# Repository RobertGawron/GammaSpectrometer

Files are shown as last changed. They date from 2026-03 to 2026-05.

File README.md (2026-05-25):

# Silicon Photomultiplier Gamma Spectrometer

  

## Principle of operation

Gamma Spectrometer allows for the quantitative measurement of the amount of different isotopes in an analyzed sample.

It consists of a scintillator (a material that converts gamma particles into photons) and a photomultiplier that multiplies those photons and converts them into electric current pulses. By measuring the amplitude of these pulses, it is possible to calculate the original energy of the gamma ray that produced the pulse.

Sampling data over time and plotting its histogram reveals which radioactive isotopes are present in the measured sample and their respective ratios.

[More info.](./02_SystemArchitecture/SystemTheory/README.md)

## System Architecture and Technical Decisions

### Silicon photomultiplier vs traditional PMT

Conventional gamma spectrometers commonly use vacuum photomultiplier tubes (PMTs). These require high-voltage supplies in the kilovolt range, are mechanically fragile, and are sensitive to magnetic fields.

In this project, a Silicon Photomultiplier (SiPM) is used instead. The SiPM operates at significantly lower bias voltage (tens of volts rather than kilovolts), is mechanically robust, compact, and insensitive to magnetic fields. These characteristics simplify the power supply design and mechanical integration.

### Digital vs analog processing

Traditional spectrometers implement CR-RC shaping networks and peak detection entirely in analog hardware. This approach is cost-effective but offers limited flexibility, as parameter changes require hardware modification.

In this system, pulse shaping and peak detection are performed digitally after high-speed sampling. This increases flexibility and allows signal processing parameters to be modified in firmware without hardware changes. The trade-off is higher performance requirements for the ADC and the need for an FPGA rather than a microcontroller, which increases overall system cost.

## Hardware design verification

Hardware design analysis is performed using LTspice for circuit simulation and a Jupyter-based framework for numerical post-processing. These tools are used to validate the interaction between the SiPM, the analog front-end, and the system timing behavior before to PCB design. The goal is to verify theoretical models, evaluate noise and bandwidth limitations, and confirm that design requirements are satisfied.

[More info.](./05_Verification/ElectronicHardware/Simulation/README.md)

## Hardware

Architecture Overview

Tools: KiCad.

[More info.](./03_SubsystemDesign/ElectronicHardware/README.md)

## Software

Target FPGA: iCE40.

The project is developed using a **completely open-source** FPGA toolchain containerized in Docker.

* RTL Language: VHDL-2008
* Synthesis: [Yosys](https://github.com/YosysHQ/yosys), [GHDL](https://github.com/ghdl/ghdl)
* Place & Route: [nextpnr](https://github.com/YosysHQ/nextpnr)
* Formal Verification: [SymbiYosys](https://github.com/YosysHQ/sby), PSL assertions
* Unit Testing Framework: [VUnit](https://vunit.github.io/)

[More info.](./03_SubsystemDesign/DigitalLogic/README.md)

## Mechanical

The analog frontend requires a metal chassis for protection from electromagnetic interference and external light sources.

The scintillator crystal is mounted inside using a 3D-printed stand.

The crystal and SiPM are optically coupled using optical gel to minimize light pulse reflections at the interface

Tools: OpenSCAD and FreeCAD.

Picture below shows a render of the holder for the scintillator crystal.

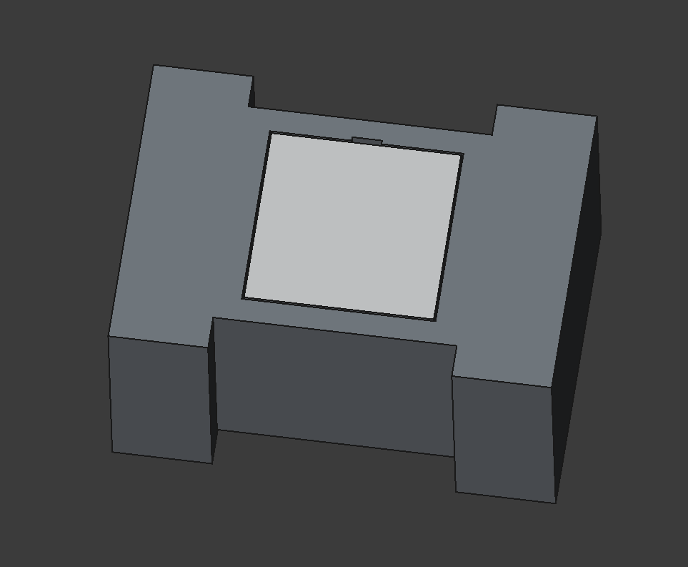
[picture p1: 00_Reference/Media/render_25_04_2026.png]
3d printed holder


[More info.](./03_SubsystemDesign/DetectorAssembly/README.md)

## DevOps

The development environment is containerized using Docker to avoid polluting the host machine with all the necessary software. The only two software tools that are not containerized are LTspice and KiCad.

[More info.](./07_DevOps/README.md)

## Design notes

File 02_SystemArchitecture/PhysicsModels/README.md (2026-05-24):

# Detector Architecture Studies

## Purpouse

The objective is to establish detector physics limits and evaluate
whether electronic performance exceeds fundamental scintillation limits.

$$
\sigma_{electronics} \ll \sigma_{scintillation}
$$

The detector physics sets the floor, electronics should not dominate it.
Anything significantly exceeding this margin is cost overhead, not performance gain.

---

## Study Index

| Study | File | Description |
|---|---|---|
| resolution_geometry_study | Analysis.ipynb | Resolution vs crystal/SiPM geometry |
| sipm_array_spectrum | Analysis.ipynb | Spectrum vs SiPM array size |
| dark_count | Analysis.ipynb | Temperature-dependent dark noise impact |

---

## Study 1 -- Resolution Geometry Study

### Question

How does crystal diameter and SiPM size affect statistical energy resolution?

### Parameters Swept

    Crystal diameters : [25.4, 38.0, 50.0] mm
    SiPM sizes        : [6.0, 10.0, 25.4] mm
    Scintillators     : NaI(Tl), LaBr3(Ce)

### Fixed Parameters

    Reference energy    : 0.662 MeV
    PDE                 : 0.35
    Optical efficiency  : 0.70

### Output

resolution_geometry_study

### Key Findings

* Larger SiPM relative to crystal -> better coverage -> lower FWHM
* LaBr3(Ce) consistently outperforms NaI(Tl) due to higher light yield
* At small crystal diameter (25.4 mm), even 6x6 mm SiPM gives meaningful coverage
* At large crystal diameter (50.0 mm), coverage drops significantly unless SiPM size is matched

---

## Study 2 -- SiPM Array Spectrum Study

### Scientific Question

How does increasing the number of SiPMs affect observable spectral peak separation and resolution?

### Resolution Scaling Model

Adding N identical SiPMs in parallel scales resolution as:

    FWHM(N) = FWHM_single / sqrt(N_sipm)

### SiPM Configurations Compared

    1 x 6x6 mm  ->  n_sipm = 1
    4 x 6x6 mm  ->  n_sipm = 4
    6 x 6x6 mm  ->  n_sipm = 6

### Output

sipm_array_spectrum
   
### Key Findings

    * Array scaling gives diminishing returns beyond ~4 SiPMs
    * Peak separation becomes clearly visible at n_sipm = 4
    * Background rate has visible impact at low-energy lines

---

## Study 3 -- Dark Count Noise Study

### Question

At what temperature does dark count noise begin to degrade
low-energy gamma detection?

### SiPM Device

    ON Semiconductor MICROFC-60035-SMT
    Active area  : 6 x 6 mm
    Microcell    : 35 um pitch
    Array config : 4 x SiPM

### Temperature Points

    [3, 21, 35] degC

### Low-Energy Isotopes Simulated

    Fe-55   :  5.9 keV
    Am-241  : 13.5 keV
    Cd-109  : 22.0 keV
    Ba-133  : 30.0 keV
    Am-241  : 59.5 keV

### Output

spectrum_dark_count_MICROFC60035

### Key Findings

    - Dark count rate increases significantly with temperature
    - At 35degC the noise floor begins to obscure sub-10 keV lines
    - Cooling to 3degC substantially suppresses the noise continuum

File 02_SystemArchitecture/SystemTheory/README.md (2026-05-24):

# Theoretical background

## Purpose
This folder contains the theoretical foundation for the SiPM-based gamma spectrometer.

It defines the mathematical models, signal relationships, and performance limits governing the detector, analog front-end (AFE), clocking, and ADC stages.

---

## Document Structure

* [SiPM and Charge Amplifier Readout](./SiPMAndCSA.md) - defines the detector and analog front-end signal model.
  * SiPM gain and charge generation: $$Q_{total} = N \cdot G \cdot q_e$$
  * Equivalent SiPM capacitance ($C_{SiPM}$)
  * Microcell recharge time constant ($\tau_{cell}$)
  * Charge-to-voltage conversion: $$V_{out} = \frac{Q_{in}}{C_f}$$
  * Feedback component relationships ($R_f, C_f$)

* [Analog Noise Analysis and Energy Resolution](./AnalogNoiseAnalysis.md) - defines the system noise budgeting methodology.
  * RMS noise definition and spectral density integration: $$V_{rms} = \sqrt{\int S_v^2(f) \, df}$$
  * Differential noise treatment
  * Input-referred noise (CSA and TIA)
  * Equivalent Noise Charge (ENC)
  * Root-sum-square (RSS) noise combination
  * ENOB conversion from SNR: $$ENOB = \frac{SNR - 1.76}{6.02}$$
  * Impact of electronic noise on energy resolution

* [Signal Processing and Sampling Theory](./SignalProcessingAndSampling.md)
  - Bandwidth vs rise time relationship:
    $$t_r \approx \frac{0.35}{f_{3dB}}$$
  - Sampling constraints and discrete-time representation
  - Rule of Three for amplitude reconstruction
  - Samples per pulse:
    $$N_{pulse} = \frac{5\tau}{T_s}$$
  - Digital integration SNR improvement:
    $$SNR \propto \sqrt{N}$$
  - Oversampling ratio:
    $$OSR = \frac{f_s}{2 \cdot BW}$$

* [Clock Jitter and SNR Limitation](./ClockJitterAnalysis.md) - defines timing-related performance limitations.
  * RMS jitter definition ($\sigma_t$)
  * Jitter-induced amplitude error derivation
  * Jitter-limited SNR equation: $$SNR_{jitter} = -20 \log_{10}(2\pi f_{in} \sigma_t)$$
  * ENOB relationship
  * Combination of multiple jitter sources (RSS combination)

* [ENOB and ADC Performance Limitations](./ENOBAndADCPerformance.md) - defines ADC-driven system constraints.
  * Ideal quantization SNR: $$6.02N + 1.76$$
  * Practical ENOB limits based on datasheet SNR
  * Margin definition ($\Delta$) for system design
  * Derivation of allowable noise from ENOB target: $$V_{noise,max} = \frac{V_{signal,rms}}{10^{SNR/20}}$$

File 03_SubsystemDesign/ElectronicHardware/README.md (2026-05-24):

# Purpose

The hardware consists of four main parts:

***Analog Processing***

Handles low-level currents produced by the sensor (typically 1uA - 1mA pulses, 10mV - 1V after amplification):

* **[LYSO Scintillator Crystal](https://www.ebay.fr/itm/251986066149)** - Converts gamma rays into visible light pulses through scintillation. The project uses eight crystals, each 22mm x 4mm x 4mm, stacked together into a single crystal assembly with a size of 22mm x 8mm x 16mm.
* **Silicon Photomultiplier: [MICROFC-60035-SMT-TR1 SiPM](https://www.onsemi.com/pdf/datasheet/microc-series-d.pdf)** - Converts light pulses from the scintillator crystal into electrical current pulses. The project uses four SiPMs in two channels; each channel contains two SiPMs in parallel.
* **Amplifier: [LTC6268-10](https://www.analog.com/media/en/technical-documentation/data-sheets/626810f.pdf)** -  can be configured either as a charge amplifier or as a transimpedance amplifier (TIA), depending on the selected feedback network. In the current design, the amplifier is configured as a charge amplifier.
  * **Charge Amplifier Configuration.** In this mode, the amplifier integrates the input current pulse generated by the SiPM and converts the total collected charge into a proportional output voltage.
    The output voltage is defined by the feedback capacitor:

    $$V_{out} = \frac{Q}{C_f}$$

    This can also be expressed as:

    $$V_{out} = \frac{1}{C_f} \int I(t) \, dt$$

    Where:
    
    **$Q_{in}$**: The total charge generated by the Silicon Photomultiplier (SiPM).

    **$C_f$**: The feedback capacitance of the integrator or transimpedance stage.

    **$I(t)$**: The time-dependent input current pulse from the detector.

  * **Transimpedance Amplifier (TIA) Configuration.** In this configuration, the output voltage is proportional to instantaneous input current:

    $$V_{out} = -I_{in} \cdot R_f$$

    Where:

    **$R_f$**: The feedback resistor that determines the gain of the transimpedance stage.

    **$I_{in}$**: The instantaneous input current flowing from the sensor into the amplifier.

* **Differential ADC Driver: [AD8139](https://www.analog.com/media/en/technical-documentation/data-sheets/AD8139.pdf)** - Converts the single-ended amplifier output into a differential signal suitable for the ADC input. It also sets the required common-mode voltage (1.5 V) needed by ADC.
* **Bias Supply** - Provides a stable and filtered 29 V bias voltage for the SiPM. The bias voltage is adjustable to compensate for temperature-dependent gain variation of the SiPM.
   * [MCP3221](https://ww1.microchip.com/downloads/en/devicedoc/20001732e.pdf) 12-bit I2C ADC measures the SiPM temperature via a thermistor. Since the SiPM gain varies with temperature, this measurement is used by FPGA to adjust the bias voltage
   * [MCP4725xxx-xCH](https://ww1.microchip.com/downloads/en/devicedoc/22039d.pdf) 12-bit I2C DAC generates a control voltage used to adjust the SiPM bias supply. This allows the FPGA to compensate temperature-induced gain variations of SiPM.
   * [LT8330IS6](https://www.analog.com/media/en/technical-documentation/data-sheets/lt8330.pdf) - dc/dc converter generates the raw high-voltage supply for the SiPM bias circuit.
   * [TPS7A49](https://www.ti.com/lit/ds/symlink/tps7a49.pdf?ts=1776866743000) - filters and regulates the output of the DC/DC converter, providing a low-noise and stable bias voltage for the SiPM. The output voltage is adjustable via the compensation DAC.
   * **Overcurrent Protection (TBD)** - Cuts bias voltage if SiPM is exposed to external light source, preventing sensor damage from excessive photocurrent

> **Note:** Analog pulse shaping and peak detection are not used - raw signal is digitized directly and processed in FPGA.

***Digital processing***

Performs high-speed sampling and real-time pulse analysis:

* **ADC: [AD9238](https://www.analog.com/media/en/technical-documentation/data-sheets/ad9238.pdf)** - 2-channel, 12-bit, 40 MSPS sampling rate. ch channel produces 480 Mbps (60 MB/s), resulting in 960 Mbps (120 MB/s) total sample data rate.
* **FPGA: [iCE40HX4K](https://www.latticesemi.com/en/Products/FPGAandCPLD/iCE40#_21E33C7EC0BD48AA80FE384ED73CC895)** - Real-time digital pulse processing (trapezoidal filtering, peak detection, histogram generation)
* **SPI Flash: [MX25L1606EM1I-12G](https://www.tme.eu/Document/90cf95a7114025302d33a68125e207ab/MX25L1606E.pdf)** - Stores FPGA configuration bitstream
* **SPI Port** - External header for FPGA programming
* **UART to USB Converter: [CH340X](https://cdn.sparkfun.com/assets/5/0/a/8/5/CH340DS1.PDF)** - Communication interface to PC.

**Clock Subsystem**

* [511JCA40M0000BAG](https://eu.mouser.com/datasheet/3/564/1/si510_11.pdf) 40MHz, 0.8ps Nom / 1ps Max jitter LVDS clock
* [SI53340-B-GM](https://eu.mouser.com/datasheet/3/564/1/Si5334x_datasheet.pdf)
* [PI6C49CB01Q2WEX](https://4donline.ihs.com/images/VipMasterIC/IC/DIOD/DIOD-S-A0009189280/DIOD-S-A0009189280-1.pdf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)

**Power Distribution**
* to be refined

# Circuit

Circuit

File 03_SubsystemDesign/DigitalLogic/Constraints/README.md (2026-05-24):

# Constraints

Constraint files for FPGA implementation, including:
* pin assignments
* timing constraints
* clock constraints
* location constraints
* I/O standards
* tool-specific constraints

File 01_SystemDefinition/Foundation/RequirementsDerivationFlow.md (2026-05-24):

## Purpose

This document is [the foundation for requirement IDs](../Requirements/)

---

## Derivation Flow

| Step | Detail / Value |
| :--- | :--- |
| **Measurement Intent** | First HW version, capability to be determined experimentally. |
| **Scintillator Selection** | NaI(Tl) 25.4 mm diameter, light yield 38,000 ph/MeV, cost-effective, good timing (230 ns decay) |
| **SiPM Selection** | 4 x MICROFC-60035-SMT (6x6 mm each), PDE 35%, cost-effective, effective coverage 28.4% |
| **Detector Physics Analysis** ($\sigma_{scintillation}$ calculated) | N_detected = 1755 PE @ 662 keV, $\sigma_{scintillation} = 2.39\%$, FWHM_statistical = 5.6% |
| **Electronics Noise Budget** ($\sigma_{electronics} \leq 0.18 \times \sigma_{scintillation}$) | Derived: $\sigma_{electronics} \leq 0.43\%$ RMS; Total degradation < 1.5% acceptable |
| **Bandwidth Derived** (from pulse shape) | SiPM t_cell = 95 ns -> f_-3dB ~= 3.5 MHz; ADC sampling at 40 MSPS adequate for pulse reconstruction |
| *ADC* | 12-bit, 40 MSPS |

**Detector Physics Analysis and Requirements Derivation**
(See: [Detector Physics Analysis and Requirements Derivation](./DetectorPhysicsAnalysis.md))

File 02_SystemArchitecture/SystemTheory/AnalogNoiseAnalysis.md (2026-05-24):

# Analog Noise Analysis and Energy Resolution

## 1. Purpose

Basis for analyzing analog front-end (AFE) noise.

---

## 2. Definitions

### 2.1 Noise Spectral Density and RMS Integration
Voltage noise spectral density $S_v(f)$ is expressed in units of:

$$\text{V} / \sqrt{\text{Hz}}$$

The RMS noise over a defined bandwidth from $f_{low}$ to $f_{high}$ is:

$$V_{rms} = \sqrt{\int_{f_{low}}^{f_{high}} S_v^2(f) \, df}$$

**Principles:**
* Spectral density must be squared before integration (working in the power domain).
* Integration must be performed in the linear domain.
* RMS noise is strictly bandwidth dependent.
* Integration limits must always be explicitly stated.

---

### 2.2 Bandwidth Definition
The integration bandwidth shall match the effective system bandwidth. For an ADC sampling at $f_s$:

$$f_{Nyquist} = \frac{f_s}{2}$$

Noise shall be integrated from DC to Nyquist unless limited by an analog anti-alias filter. If an anti-alias filter is present, the shaped spectral density is used:

$$S_{v,shaped}(f) = |H(f)| \cdot S_v(f)$$

The resulting $S_{v,shaped}^2(f)$ shall be used in the integration defined in Section 2.1.

---

### 2.3 Differential Noise
For differential ADC inputs:

$$V_{diff}(t) = V_P(t) - V_N(t)$$

All RMS noise calculations relevant to ADC performance shall be performed on the differential signal. The integration method defined in Section 2.1 applies to the differential spectral density.

---

### 2.4 Input-Referred Noise
The total integrated RMS noise may be referred to the detector domain.

**Transimpedance Amplifier (TIA):**

$$I_{noise,rms} = \frac{V_{noise,rms}}{R_f}$$

**Charge-Sensitive Amplifier (CSA):**

$$Q_{noise,rms} = V_{noise,rms} \cdot C_f$$

**Convert charge noise to electrons ($N_e$):**

$$N_e = \frac{Q_{noise,rms}}{e}$$

Where $e = 1.602 \times 10^{-19} \text{ C}$. This quantity represents the complete integrated analog front-end noise referred to the detector input.

---

### 2.5 Total RMS Noise (RSS Combination)
Independent noise sources shall be combined in variance form:

$$V_{total,rms} = \sqrt{V_1^2 + V_2^2 + V_3^2 + \dots}$$

**Assumptions:**
* Statistical independence.
* Gaussian distribution.
* No deterministic correlation.
* **Note:** Noise powers add, not amplitudes.

---

### 2.6 Integrated Noise vs Frequency (Cumulative Form)
To evaluate noise contribution as a function of bandwidth:

$$V_{rms}(f) = \sqrt{\int_{f_{low}}^{f} S_v^2(f') \, df'}$$

This representation allows for the identification of dominant frequency regions and verification of anti-alias filter effectiveness.

---

### 2.7 Conversion to SNR and ENOB
**Signal-to-Noise Ratio (SNR):**

$$SNR = 20 \log_{10} \left( \frac{V_{signal,rms}}{V_{noise,rms}} \right)$$

**Effective Number of Bits (ENOB):**

$$ENOB = \frac{SNR - 1.76}{6.02}$$

---

### 2.8 Equivalent Noise Charge (ENC)
For charge-based systems:

$$Q_{noise} = I_{noise,rms} \cdot \tau$$

$$N_e = \frac{Q_{noise}}{e}$$

**Where:**
* $\tau$: Shaping time constant.
* $e$: Elementary charge.

ENC provides a direct linkage between electronic noise and spectroscopy energy resolution.

---

### 2.9 Scintillation Statistical Limit

From Poisson statistics, the relative energy resolution is limited by the number of scintillation photons:

$$\frac{\sigma_E}{E} \propto \frac{1}{\sqrt{N_{ph}}}$$

This represents the **fundamental detector limit**.

Even with perfect electronics, the resolution cannot exceed this bound.

---

### 2.10 Electronics Contribution

Electronic noise introduces additional variance:

$$\sigma_{electronics}$$

Total variance combines in quadrature:

$$\sigma_{total}^2 = \sigma_{scintillation}^2 + \sigma_{electronics}^2$$

---

### 2.11 Physics-Limited Regime

If:

$$\sigma_{electronics} \ll \sigma_{scintillation}$$

Then:

$$\sigma_{total} \approx \sigma_{scintillation}$$

In this regime, system performance is limited by scintillator physics rather than electronics.

The design goal of the analog front-end is therefore to ensure:

$$ENC_{electronics} \ll ENC_{detector}$$
ENC provides a direct linkage between electronic noise and system energy resolution.

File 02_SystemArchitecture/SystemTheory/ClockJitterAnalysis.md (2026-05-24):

# Clock Jitter and SNR Limitation

## 1. Purpose

Theoretical basis for clock jitter analysis.

---

## 2. Definitions

### 2.1 Signal-to-Noise Ratio (SNR)

In power terms:

$$
\mathrm{SNR} = \frac{P_{\mathrm{signal}}}{P_{\mathrm{noise}}}
$$

In decibel form:

$$
\mathrm{SNR}_{dB} = 10 \log_{10}\left(\frac{P_{\mathrm{signal}}}{P_{\mathrm{noise}}}\right)
$$

For voltage quantities (equal impedance):

$$
\mathrm{SNR}_{dB} = 20 \log_{10}\left(\frac{V_{\mathrm{signal,rms}}}{V_{\mathrm{noise,rms}}}\right)
$$

---

### 2.2 RMS Clock Jitter

RMS jitter represents the statistical standard deviation of sampling time uncertainty.

If an ideal sampling instant occurs at time $t_0$, the actual sampling time is:

$$
t = t_0 + \Delta t
$$

where $\Delta t$ is a random timing deviation.

The RMS jitter is defined as:

$$
\sigma_t = \sqrt{E[(\Delta t)^2]}
$$

where $E[\cdot]$ denotes the expectation operator.

---

## 2.3 Derivation of Jitter-Limited SNR

Consider a sinusoidal input signal:

$$
x(t) = A \sin(2\pi f_{in} t)
$$

If sampling occurs with time error $\Delta t$, the amplitude error is:

$$
\Delta x = \frac{dx}{dt} \cdot \Delta t
$$

The derivative of the signal is:

$$
\frac{dx}{dt} = A \cdot 2\pi f_{in} \cos(2\pi f_{in} t)
$$

Thus:

$$
\Delta x = A \cdot 2\pi f_{in} \cos(2\pi f_{in} t) \cdot \Delta t
$$

The RMS value of $\cos(\cdot)$ is $1/\sqrt{2}$.

Therefore, jitter-induced RMS noise is:

$$
V_{\mathrm{jitter,rms}} = \frac{A}{\sqrt{2}} \cdot 2\pi f_{in} \sigma_t
$$

Signal RMS:

$$
V_{\mathrm{signal,rms}} = \frac{A}{\sqrt{2}}
$$

Thus:

$$
\mathrm{SNR} = \frac{V_{\mathrm{signal,rms}}}{V_{\mathrm{jitter,rms}}}
= \frac{1}{2\pi f_{in} \sigma_t}
$$

In decibel form:

$$
\mathrm{SNR}_{dB} = -20 \log_{10}(2\pi f_{in} \sigma_t)
$$

This shows jitter-induced SNR degradation increases linearly with input frequency.

---

## 2.4 Derivation of ENOB Formula

For an ideal N-bit ADC with full-scale peak-to-peak range $V_{FS,pp}$:

$$
\mathrm{LSB} = \frac{V_{FS,pp}}{2^N}
$$

Quantization noise RMS (uniform distribution):

$$
V_{q,rms} = \frac{\mathrm{LSB}}{\sqrt{12}}
$$

For a full-scale sine wave:

$$
V_{\mathrm{signal,rms}} = \frac{V_{FS,pp}}{2\sqrt{2}}
$$

Thus:

```math
\mathrm{SNR} =
\frac{V_{\mathrm{signal,rms}}}{V_{q,rms}}
=
\frac{\frac{V_{FS,pp}}{2\sqrt{2}}}
{\frac{V_{FS,pp}}{\sqrt{12} \cdot 2^N}}
=
\sqrt{\frac{3}{2}} \cdot 2^N
```

In decibel form, the ideal SNR for an $N$-bit converter is:

$$SNR_{dB} = 6.02N + 1.76$$

Rearranging to solve for the **Effective Number of Bits (ENOB)** based on measured SNR:

$$ENOB = \frac{SNR_{dB} - 1.76}{6.02}$$

## 2.5 Total SNR Combination
When multiple independent noise sources exist (e.g., ADC intrinsic noise and jitter noise), noise powers add in the linear domain.

If:

$$SNR_{ADC}$$
$$SNR_{jitter}$$

Then:

$$\frac{1}{SNR_{total,linear}} = \frac{1}{SNR_{ADC,linear}} + \frac{1}{SNR_{jitter,linear}}$$

Where:
$$SNR_{linear} = 10^{SNR_{dB}/10}$$

Convert back:

$$SNR_{total,dB} = 10 \log_{10}(SNR_{total,linear})$$

Noise powers must always be summed in linear scale.

---

## 2.6 RSS Jitter Combination
If multiple independent RMS jitter sources exist:

$$\sigma_{total} = \sqrt{\sigma_1^2 + \sigma_2^2 + \sigma_3^2 + \dots}$$

This follows from variance addition:

$$\sigma_{total}^2 = \sigma_1^2 + \sigma_2^2 + \sigma_3^2 + \dots$$

Valid only for uncorrelated jitter sources.

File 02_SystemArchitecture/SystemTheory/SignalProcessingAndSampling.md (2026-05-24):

# Signal Processing and Sampling Theory

## 1. Purpose

Defines the relationship between analog bandwidth, pulse dynamics, sampling rate, digital reconstruction, and processing gain.

This document covers the time-domain and discrete-time constraints of the spectroscopy system.

---

## 2. Bandwidth and Rise Time Relationship

For a first-order system:

$$t_r \approx \frac{0.35}{f_{3dB}}$$

Where:
* $t_r$: 10%-90% rise time.
* $f_{3dB}$: -3 dB bandwidth.

The constant arises from:

$$t_r = \frac{\ln(9)}{\omega_{3dB}} = \frac{2.2}{2\pi f_{3dB}}$$

Engineering Interpretation:
* Higher bandwidth -> faster rise time.
* Excess bandwidth increases integrated noise.

Bandwidth must preserve signal dynamics without unnecessarily increasing noise.

---

## 3. Sampling Theory

ADC sampling frequency:

$$f_s$$

Sampling period:

$$T_s = \frac{1}{f_s}$$

Samples across rising edge:

$$N_{rise} = \frac{t_r}{T_s}$$

---

## 4. The Rule of Three

For reliable amplitude estimation:

$$N_{rise} \ge 3$$

Reason:
* 1 sample -> no slope information.
* 2 samples -> unstable interpolation.
* 3+ samples -> reliable curve fitting and peak detection.

This requirement arises from discrete-time approximation limits.

---

## 5. Total Samples per Pulse

Pulse duration approximately:

$$T_{pulse} \approx 5\tau$$

Total samples per pulse:

$$N_{pulse} = \frac{5\tau}{T_s}$$

Determines:
* Digital integration capability
* Energy estimation stability
* Pile-up discrimination

---

## 6. Digital Integration and SNR Improvement

When integrating $N$ independent samples:

$$SNR \propto \sqrt{N}$$

Because:

$$\sigma_{avg} = \frac{\sigma}{\sqrt{N}}$$

Oversampling improves effective resolution through processing gain.

---

## 7. ADC Resolution vs Sampling Rate

Two orthogonal improvement mechanisms:

Increasing ADC bits:
* Reduces quantization noise
* Improves SNR by ~6 dB per bit

Increasing sampling rate:
* Increases $N$
* Improves SNR by $\sqrt{N}$ after integration

Total system variance:

$$\sigma_{total}^2 = \sigma_{detector}^2 + \sigma_{AFE}^2 + \sigma_{ADC}^2 + \sigma_{quantization}^2$$

Dominant variance determines performance limit.

---

## 8. Oversampling Ratio (OSR)

$$OSR = \frac{f_s}{2 \cdot BW}$$

Higher OSR:
* Improves digital filtering flexibility
* Reduces in-band noise after decimation
* Improves amplitude estimation stability

ADC speed enables digital processing gain even if analog bandwidth is lower.

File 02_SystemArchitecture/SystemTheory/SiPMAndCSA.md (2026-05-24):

# SiPM and Charge Amplifier Readout

## 1. Purpose
Theoretical background of the Silicon Photomultiplier (SiPM) and its readout using a charge-sensitive amplifier.

---
## 2. Definitions

### 2.1 Silicon Photomultiplier (SiPM) Operation

When a photon is absorbed in a microcell, it may trigger an avalanche process, producing a fixed amount of charge. The charge generated by a single avalanche event is given by:

$$Q_{1ph} = G \cdot q_e$$

**Where:**
* $G$: SiPM gain (number of charge carriers generated during one avalanche event).
* $q_e$: Elementary charge ($1.602 \times 10^{-19}$ C).

> **Note:** The gain $G$ is typically provided in the device datasheet and depends on the applied overvoltage.

For multiple detected photons:

$$Q_{total} = N \cdot G \cdot q_e$$

**Where:**
* $N$: Number of triggered microcells (approximately equal to detected photons under low light conditions).

Thus, the SiPM behaves as a quantized charge generator.

---

### 2.2 SiPM Capacitance
Since all microcells are connected in parallel, the SiPM exhibits a total equivalent capacitance ($C_{SiPM}$). This capacitance arises from the junction capacitance of each microcell and the parallel combination of all cells.

$C_{SiPM}$ influences:
* Bandwidth
* Noise
* Stability of the front-end amplifier

In a charge amplifier configuration, however, the gain does not depend directly on $C_{SiPM}$.

---

### 2.3 Microcell Recharge Time Constant
After an avalanche event, each microcell must recharge through its internal quench resistor. This follows exponential recovery behavior characterized by the microcell time constant:

$$\tau_{cell} = R_q \cdot C_{cell}$$

**Where:**
* $R_q$: Internal quench resistor.
* $C_{cell}$: Microcell capacitance.

> **Note:** The gain $\tau_{cell}$ is typically provided in the device datasheet.

The value of $\tau_{cell}$ affects the maximum count rate, pulse shape, and dynamic response.

---

### 2.4 Charge Amplifier Principle
To convert the SiPM charge pulse into a measurable voltage, a charge-sensitive amplifier (CSA) is used. In an ideal charge amplifier:

$$V_{out} = \frac{Q_{in}}{C_f}$$

Substituting the SiPM charge expression:

$$V_{out} = \frac{N \cdot G \cdot q_e}{C_f}$$

**This shows that:**
1. The output voltage is proportional to the number of detected photons.
2. The gain is determined only by the feedback capacitor $C_f$.
3. The detector capacitance $C_{SiPM}$ does not set the signal amplitude.

---

### 2.5 Feedback Capacitor ($C_f$)
In a charge-sensitive amplifier (CSA), the output voltage is determined by the input charge and the feedback capacitance:

$$V_{out} = \frac{Q_{in}}{C_f}$$

For an SiPM, the input charge generated by $N$ detected photons is:

$$Q_{in} = N \cdot G \cdot q_e$$

Combining both equations:

$$V_{out} = \frac{N \cdot G \cdot q_e}{C_f}$$

Rearranging to determine the required feedback capacitance for a specific target voltage:

$$C_f = \frac{N \cdot G \cdot q_e}{V_{out}}$$

**Thus, the feedback capacitor is selected based on:**
* Expected maximum number of detected photons ($N$).
* SiPM gain ($G$) from the datasheet.
* Desired output voltage amplitude ($V_{out}$).

The value of $C_f$ directly sets the charge-to-voltage conversion gain of the system.

---

### 2.6 Feedback Resistor ($R_f$)
The feedback resistor determines the discharge rate of the feedback capacitor and therefore the pulse decay time. The decay time constant of the charge amplifier is:

$$\tau = R_f \cdot C_f$$

To ensure accurate charge integration, the amplifier time constant is chosen relative to the SiPM microcell recharge time constant ($\tau_{cell}$):

$$\tau \ge k \cdot \tau_{cell}$$

**Where:**
* $\tau_{cell}$ is provided in the datasheet.
* $k$ is typically selected between 3 and 5.

Solving for the feedback resistor:

$$R_f = \frac{\tau}{C_f}$$

Once $C_f$ is determined and the desired shaping time $\tau$ is selected, the required feedback resistor can be calculated.

Design Considerations
* **$C_f$**: Defines signal amplitude and dynamic range. Larger capacitance prevents saturation but lowers sensitivity.
* **$R_f$**: Defines pulse width and maximum count rate capability. Lower resistance allows for faster counting but may increase electronic noise.
* Both parameters must be selected considering noise, bandwidth, and stability constraints of the operational amplifier.

---

### 2.8 Detector Shot Noise (SiPM)
The dominant intrinsic noise mechanism of a SiPM is shot noise associated with dark current. The RMS shot noise current is given by:

$$i_{shot,rms} = \sqrt{2q I_{dark} \Delta f}$$

**Where:**
* $q$: Elementary charge ($1.602 \times 10^{-19} \text{ C}$).
* $I_{dark}$: Detector dark current.
* $\Delta f$: Effective noise bandwidth.

Shot noise arises from the discrete nature of charge carriers and follows Poisson statistics.

**Key Properties:**
* Shot noise is proportional to the square root of dark current.
* Shot noise increases with bandwidth.
* Shot noise is statistically independent from electronic amplifier noise.

This contribution must be included in the total noise RSS calculation when modeling full system performance.

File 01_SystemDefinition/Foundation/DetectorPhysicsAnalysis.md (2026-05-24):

# Detector Physics Analysis and Requirements Derivation

## Purpose

The objective is to establish detector physics limits and evaluate
whether electronic performance exceeds fundamental scintillation limits.

The fundamental design principle is:

$$
\sigma_{electronics} \ll \sigma_{scintillation}
$$

The detector physics sets the performance floor. Electronics should not
dominate it. Anything significantly exceeding this margin is cost overhead,
not performance gain.

---

## Design Flow Overview

The correct systems engineering flow for gamma spectrometer design:

1. Measurement Intent
2. Isotope Identification Requirements
3. Energy Resolution Requirements
4. Scintillator Selection (based on resolution, density, cost, ruggedness)
5. Crystal Geometry Selection (volume vs weight tradeoff)
6. SiPM Selection (PDE, dark count, size, radiation hardness)
7. Detector Physics Analysis (calculate sigma_scintillation)
8. Electronics Noise Budget Derivation (sigma_electronics <= 0.3 x sigma_scintillation)
9. Bandwidth Derivation (from SiPM pulse shape)
10. ADC Requirements Derivation (ENOB, sampling rate)
11. Component Selection (meets derived requirements)

---

## Section 1 - Scintillator Selection

### Selection Criteria

Scintillator selection is driven by multiple competing requirements:

| Property | Impact | Tradeoff |
|---|---|---|
| Light yield (photons/MeV) | Higher -> better resolution | Usually inversely related to density |
| Density (g/cm^3) | Higher -> better detection efficiency | Heavier, may reduce light yield |
| Decay time (ns) | Shorter -> higher count rate capability | May have lower light yield |
| Emission wavelength (nm) | Must match SiPM PDE peak | Material constraint |
| Hygroscopicity | Non-hygroscopic -> easier handling | May limit material choices |

### Common Scintillator Properties

| Material | Light Yield (ph/MeV) | Density (g/cm^3) | Decay Time (ns) | Emission Peak (nm) | Hygroscopic |
|---|---|---|---|---|---|
| NaI(Tl) | 38,000 | 3.67 | 230 | 415 | Yes |
| LaBr3(Ce) | 63,000 | 5.08 | 16 | 380 | Yes |
| CsI(Tl) | 54,000 | 4.51 | 1000 | 550 | Slightly |
| LYSO | 32,000 | 7.10 | 40 | 420 | No |
| BGO | 8,500 | 7.13 | 300 | 480 | No |

Choice: [diameter 1 inch x 1 inch NaI(Tl) Scintillator, Energy Resolution: <=7.5%@662keV(Cs-137)](https://www.ost-photonics.com/product/diameter-1-inch-x-1-inch-naitl-scintillator/)
Reason: Cost/performance ratio. Price is a key factor because scintillator crystals are expensive ($95+ USD).

## Section 2 - SiPM Selection

### Selection Criteria

| Property | Impact | Target |
|---|---|---|
| Photon Detection Efficiency (PDE) | Higher -> more detected photons -> better resolution | Match to scintillator emission |
| Active area | Larger -> better coverage -> better resolution | Match to crystal geometry |
| Dark count rate (DCR) | Lower -> less noise at low energy | Temperature-dependent |
| Microcell size | Smaller -> lower crosstalk, higher DCR | Tradeoff: 15-50 um typical |
| Gain | Higher -> easier amplification | Must not saturate electronics |
| Timing resolution | Better -> improved coincidence performance | Not critical for spectroscopy |
| Radiation hardness | Critical for high-dose environments (not the case of this spectrometer) | Mission-dependent |
| Operating voltage | Lower -> simpler bias supply | 25-35 V typical for modern SiPMs |

Choice: [MICROFC-60035-SMT](https://www.onsemi.com/pdf/datasheet/microc-series-d.pdf)
Reason: Cost/performance ratio. SiPM are expensive ($12+ USD for 6x6mm variant).

## Section 3 - Detector Physics Calculation

### Statistical Energy Resolution Model

This subsections models the theoretical lower bound on energy resolution
assuming Poisson fluctuations in the number of detected photons dominate.

---

### Step 1 - Reference Gamma Energy

For system verification and calibration:

Cs-137 reference line:

$$
E_{\gamma} = 662 \text{ keV} = 0.662 \text{ MeV}
$$

---

### Step 2 - Scintillation Photon Production

Total photons produced by scintillation:

$$
N_{photons} = LY \times E_{\gamma}
$$

Where LY is the scintillator light yield.

For selected scintillators:

| Scintillator | Calculation | N_photons |
|---|---|---|
| NaI(Tl) | 38,000 x 0.662 | 25,156 |
| LaBr3(Ce) | 63,000 x 0.662 | 41,706 |

Note: the light output of the scintillator is a function of the deposited Gamma energy.

---

### Step 3 - Optical Collection Efficiency

Not all produced photons reach the SiPM face.

Optical efficiency factor (accounts for reflector losses, absorption):

$$
\eta_{optical} \approx 0.70
$$

Geometric coverage fraction:

$$
C_{geom} = \frac{A_{SiPM}}{A_{crystal}}
$$

Effective coverage including optical transport losses:

$$
C_{eff} = C_{geom} \times \eta_{optical}
$$

Collected photons reaching SiPM active area:

$$
N_{collected} = N_{photons} \times C_{eff}
$$

---

### Step 4 - SiPM Photon Detection

Photon Detection Efficiency (PDE) from MICROFC-60035-SMT datasheet:

$$
PDE \approx 0.35
$$

Number of detected photoelectrons:

$$
N_{detected} = N_{collected} \times PDE
$$

Full expression (combining all stages):

$$
N_{detected} = LY \times E_{\gamma} \times C_{geom} \times \eta_{optical} \times PDE
$$

---

### Step 5 - Statistical Fluctuation (Poisson Statistics)

Photoelectron generation follows Poisson statistics.

Standard deviation:

$$
\sigma_{N} = \sqrt{N_{detected}}
$$

Relative RMS fluctuation:

$$
\sigma_{rel} = \frac{\sigma_{N}}{N_{detected}} = \frac{1}{\sqrt{N_{detected}}}
$$

---

### Step 6 - Convert RMS to FWHM

### Derivation of FWHM Conversion Factor

The constant 2.355 comes from Gaussian distribution geometry:

For a Gaussian with standard deviation sigma, the FWHM is:

$$
FWHM = 2\sqrt{2\ln(2)} \times \sigma \approx 2.355 \times \sigma
$$

This assumes the energy distribution is Gaussian, which is valid when:
- N_detected >> 100 (Central Limit Theorem applies)
- Poisson distribution -> Gaussian for large N

For our configuration (N_detected = 1755), this assumption is valid.

Energy resolution is conventionally expressed as Full Width at Half Maximum (FWHM).

For a Gaussian distribution:

$$
FWHM = 2.355 \times \sigma
$$

Therefore:

$$
FWHM = 2.355 \times \sigma_{rel}
$$

Convert to percentage:

$$
FWHM = \frac{2.355}{\sqrt{N_{detected}}} \times 100
$$

---

### Step 7 - Final Statistical Resolution Formula

$$
\boxed{
FWHM = \frac{2.355}{\sqrt{N_{detected}}} \times 100
}
$$

Where:

$$
N_{detected} = LY \times E_{\gamma} \times C_{geom} \times \eta_{optical} \times PDE
$$

This is the **detector statistical limit** -- the physics floor
that cannot be improved by electronics.

---

### Step 8 - Worked Example (Selected Configuration)

Configuration:

| Parameter | Value |
|---|---|
| Scintillator | NaI(Tl) |
| Light yield | 38,000 photons/MeV |
| Crystal diameter | 25.4 mm |
| SiPM model | MICROFC-60035-SMT |
| SiPM size | 6.0 x 6.0 mm |
| PDE | 0.35 |
| Optical efficiency | 0.70 |
| Reference energy | 662 keV (0.662 MeV) |

**Calculation:**

Crystal face area:

$$
A_{crystal} = \pi \times \left(\frac{25.4}{2}\right)^2 = \pi \times 12.7^2 \approx 506.7 \text{ mm}^2
$$

SiPM configuration: 4 x (6x6 mm) array

Single SiPM active area:

$$
A_{SiPM,single} = 6.0^2 = 36.0 \text{ mm}^2
$$

Total SiPM array active area:

$$
A_{SiPM,total} = 4 \times 36.0 = 144.0 \text{ mm}^2
$$

Geometric coverage:

$$
C_{geom} = \frac{144.0}{506.7} \approx 0.284 \text{ (28.4\%)}
$$

Effective coverage:

$$
C_{eff} = 0.284 \times 0.70 \approx 0.199
$$

Photons produced:

$$
N_{photons} = 38000 \times 0.662 = 25156
$$

Detected photoelectrons:

$$
N_{detected} = 25156 \times 0.199 \times 0.35 \approx 1755
$$

Statistical RMS:

$$
\sigma_{rel} = \frac{1}{\sqrt{1755}} = \frac{1}{41.89} \approx 0.0239
$$

$$
\sigma_{scintillation} = 2.39\% \text{ RMS}
$$

Statistical FWHM:

$$
FWHM = \frac{2.355}{\sqrt{1755}} \times 100 \approx 5.6\%
$$

**Result:**

For NaI(Tl) 25.4 mm + 4 x MICROFC-60035-SMT (6x6 mm array):

$$
\boxed{
\sigma_{scintillation} = 2.39\% \text{ RMS at 662 keV}
}
$$

$$
\boxed{
FWHM_{statistical} = 5.6\%
}
$$

This is the detector physics floor.

### Step 9 - SiPM Configuration Comparison

| SiPM Size | Area (mm^2) | Effective Coverage (%) | $$\sigma$$ | FWHM  |
|---|---|---|---|---|
| 3x3 mm | 9 | 1.24% | 9.56% | 22.51% |
| 6x6 mm | 36 | 4.97% | 4.78% | 11.25% |
| array of 4 x (6x6 mm) | 144 | 19.89% | 2.39% | 5.63% |

Choice: array of 4 x (6x6 mm) [MICROFC-60035-SMT](https://www.onsemi.com/pdf/datasheet/microc-series-d.pdf)
Reason: Cost/performance ratio.

### Step 10 - Model Assumptions and Limitations

This model includes **statistical photon noise only**.

Effects **NOT** included:

| Effect | Impact on Resolution |
|---|---|
| Electronic noise | Adds in quadrature: $\sigma_{total}^2 = \sigma_{scint}^2 + \sigma_{elec}^2$ |
| Dark count rate (DCR) | Adds false counts, raises low-energy noise floor |
| Optical crosstalk | Inflates apparent N_detected, degrades resolution |
| After-pulsing | Distorts pulse shape, affects energy measurement |
| Crystal non-proportionality | Introduces energy-dependent bias |
| Optical non-uniformity | Position-dependent resolution variation |
| Temperature effects on PDE | Shifts gain and resolution |
| SiPM gain non-uniformity | Cell-to-cell variation |

Therefore:

$$
FWHM_{calculated} \leq FWHM_{measured}
$$

The calculated value is a **theoretical lower bound**.

Real measured resolution will always be larger due to additional noise sources.

---

## Section 4 - Electronics Requirements Derivation

### Noise Budget Allocation

From Section 3, we determined (for 4 x 6x6 mm SiPM array):

$$\sigma_{scintillation} = 2.39\% \text{ RMS}$$

### Design Rule

To meet minimal degradation:

$$\sigma_{electronics} \leq 0.18 \times \sigma_{scintillation}$$

This ensures total degradation is limited to 1.5%:

$$\sigma_{total} = \sqrt{\sigma_{scint}^2 + \sigma_{elec}^2}$$

### Calculate Electronics Budget

$$\sigma_{electronics} \leq 0.18 \times 2.39\% = 0.43\% \text{ RMS}$$

$$\sigma_{electronics} \leq 0.43\%$$

### Verify Degradation

If electronics contributes 0.43% RMS:

$$\sigma_{total} = \sqrt{2.39^2 + 0.43^2} = \sqrt{5.71 + 0.18} = \sqrt{5.89} \approx 2.427\%$$

Degradation:

$$\frac{2.427 - 2.39}{2.39} \times 100 \approx 1.5\%$$

This meets the requirement (≤ 1.5% degradation threshold).

### Derived Requirement

$$\boxed{\sigma_{electronics} \leq 0.43 \text{ percent RMS of full-scale energy}}$$

This is traceable to detector physics.

---

### Detector-Limited SNR

Convert detector resolution to SNR:

For FWHM ~= 5.6% (4 x 6x6 mm SiPM array):

$$\sigma = \frac{FWHM}{2.355} = \frac{5.6}{2.355} \approx 2.38\%$$

Equivalent SNR:

$$SNR = \frac{1}{\sigma} = \frac{1}{0.0238} \approx 42$$

In dB:

$$SNR_{dB} = 20 \log_{10}(42) \approx 32.5 \text{ dB}$$

**The detector physics limit is approximately 32.5 dB SNR at 662 keV.**

---

### ADC Specification Comparison

Typical ADC specifications:

- Ideal ADC SNR: 65-70 dB
- Detector-limited SNR: ~32.5 dB
- Margin: ~37 dB

**Conclusion:**

The ADC intrinsic noise floor is **not** the system bottleneck.
Detector photon statistics dominate system resolution.
Even with improved detector (4 SiPM array), ADC still has ~37 dB margin.

### Important Clarification on ENOB

ENOB (Effective Number of Bits) is a **sinusoidal continuous-wave metric**
based on SNR of a full-scale sine wave.

Gamma spectroscopy resolution is a **statistical pulse-area metric**
based on Poisson photon counting.

**These are not directly equivalent.**

Blindly applying ENOB-based ADC selection can lead to over-specification
of dynamic performance relative to detector physics.

---

## Section 5 -- Bandwidth Requirements Derivation

### SiPM Microcell Pulse Physics

After a photon triggers an avalanche in a SiPM microcell:

1. Microcell capacitance discharges rapidly (~1 ns)
2. Quench resistor stops the avalanche
3. Microcell recharges exponentially toward bias voltage

The recharge voltage follows:

$$
V(t) = V_{bias} \left(1 - e^{-t / \tau_{cell}}\right)
$$

Where the cell time constant is:

$$
\tau_{cell} = R_{quench} \times C_{cell}
$$

For MICROFC-60035-SMT (from datasheet):

| Parameter | Value |
|---|---|
| Microcell recharge time constant | tau_cell ~= 95 ns |
| Anode-cathode capacitance | C = 3400 pF |
| Dark count rate (21degC) | ~100 kHz/mm^2 |

**Important:**

tau_cell = 95 ns is the exponential recharge constant of each microcell.

It defines the **pulse tail time constant** at the anode.

It does NOT mean the pulse rise time is 95 ns (rise is faster).

The tail dominates the observable pulse envelope.

**Note:** When using 4 SiPMs in parallel, the individual microcell time constant
remains the same (95 ns). The combined pulse shape is the sum of 4 independent
SiPM pulses, but the characteristic time constant does not change.

---

### ADC Sampling Constraint

Selected ADC sampling rate: 40 MSPS

Sampling period:

$$
T_s = \frac{1}{40 \times 10^6} = 25 \text{ ns}
$$

To adequately reconstruct pulse shape:

**Required: 3 to 5 samples across rising edge**

Therefore required analog rise time:

$$
t_{rise,min} = 3 \times T_s = 75 \text{ ns}
$$

$$
t_{rise,pref} = 5 \times T_s = 125 \text{ ns}
$$

Target rise time range:

$$
t_{rise} \approx 75 \text{ to } 125 \text{ ns}
$$

This naturally aligns with tau_cell ~= 95 ns.

---

### Bandwidth Derivation

Using standard rise time to bandwidth conversion:

$$
f_{3dB} \approx \frac{0.35}{t_{rise}}
$$

For t_rise = 100 ns:

$$
f_{3dB} \approx \frac{0.35}{100 \times 10^{-9}} = 3.5 \text{ MHz}
$$

**Derived Bandwidth Requirement:**

$$
\boxed{
f_{3dB} = 3 \text{ to } 6 \text{ MHz}
}
$$

**Note:** Bandwidth requirement is independent of SiPM array size.
It is determined by pulse shape (tau_cell) and ADC sampling constraints,
not by detector resolution.

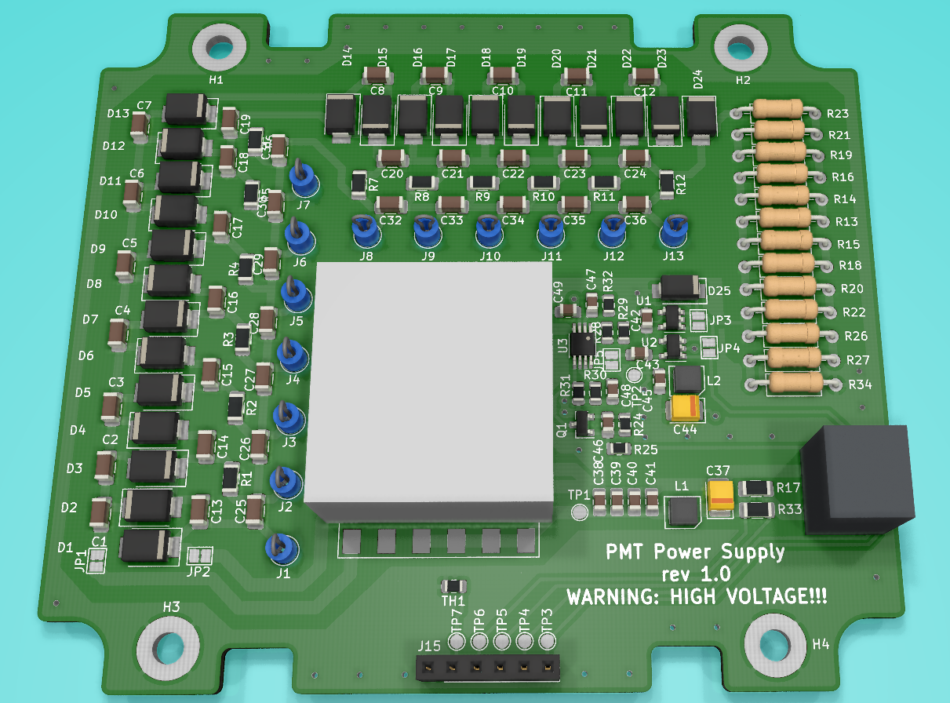
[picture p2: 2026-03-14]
00_Reference/Media/render_10_11_2020.png

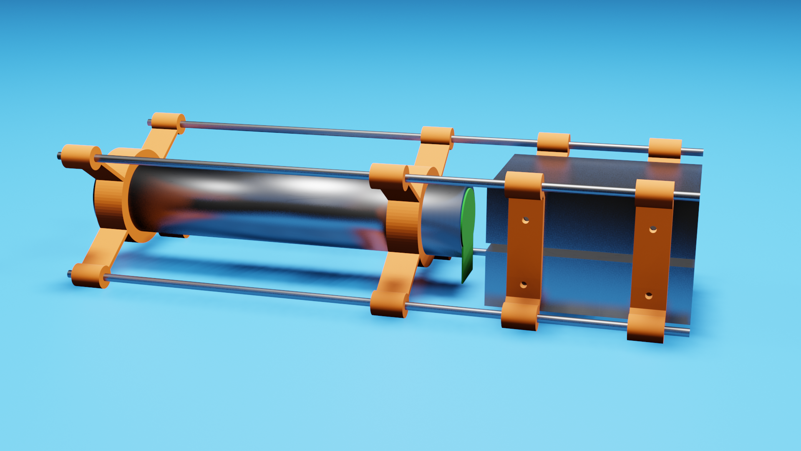
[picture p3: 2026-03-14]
00_Reference/Media/render_28_10_2020.png

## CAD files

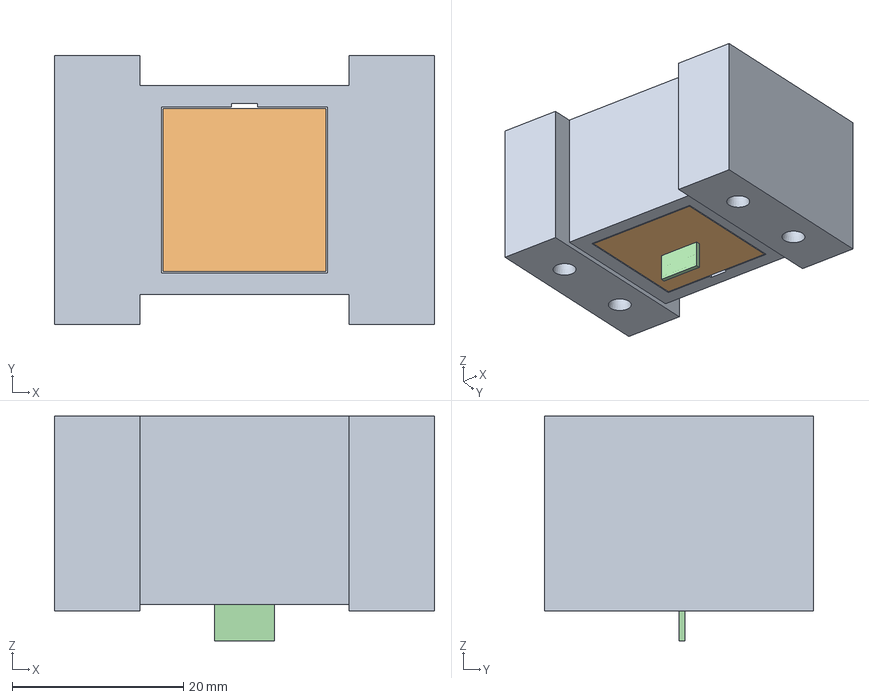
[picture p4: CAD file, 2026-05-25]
03_SubsystemDesign/DetectorAssembly/01_Models_Source/02_FreeCAD/01_ScintillationCrystalHolder/Main.FCStd
44.4 x 31.4 x 26.2 mm
MICROFC-60035-SMT-TR1
MICROFC-60035-SMT-TR002
MICROFC-60035-SMT-TR003
MICROFC-60035-SMT-TR004

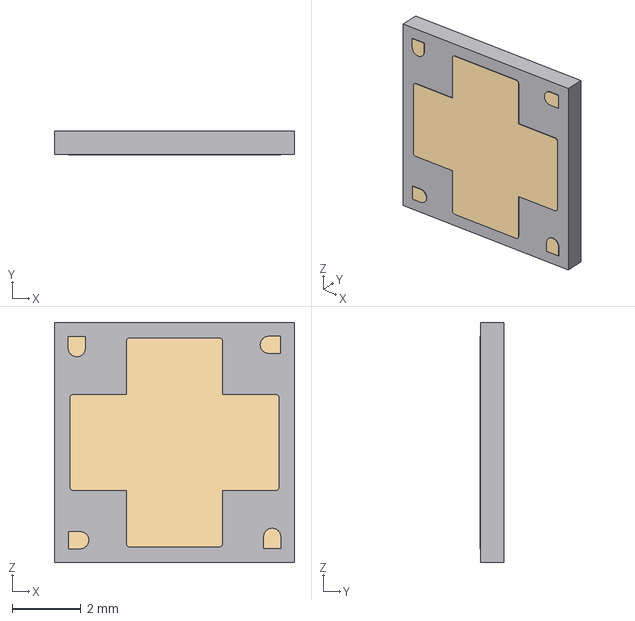
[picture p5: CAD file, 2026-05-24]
03_SubsystemDesign/DetectorAssembly/02_Models_COTS/MICROFC-60035-SMT-TR1.stp
7.00 x 0.7 x 7.00 mm

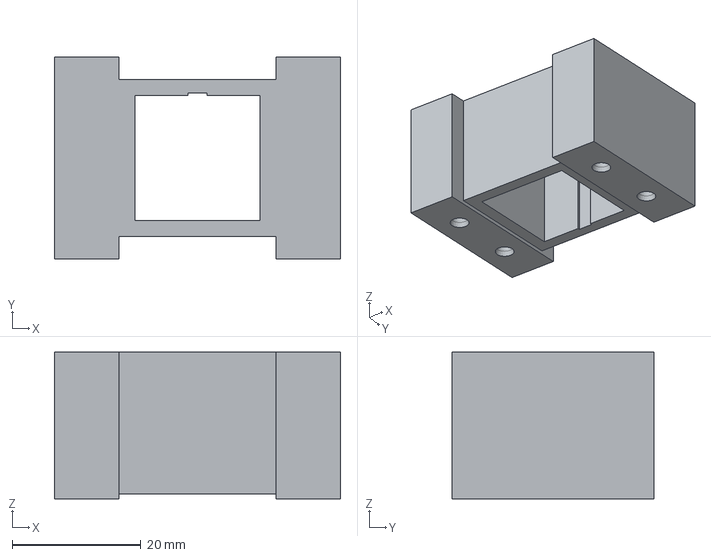
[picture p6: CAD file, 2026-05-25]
04_Implementation/DetectorAssembly/Manufacturing/STEP/01_ScintillationCrystalHolder/Holder.step
44.4 x 31.4 x 22.8 mm

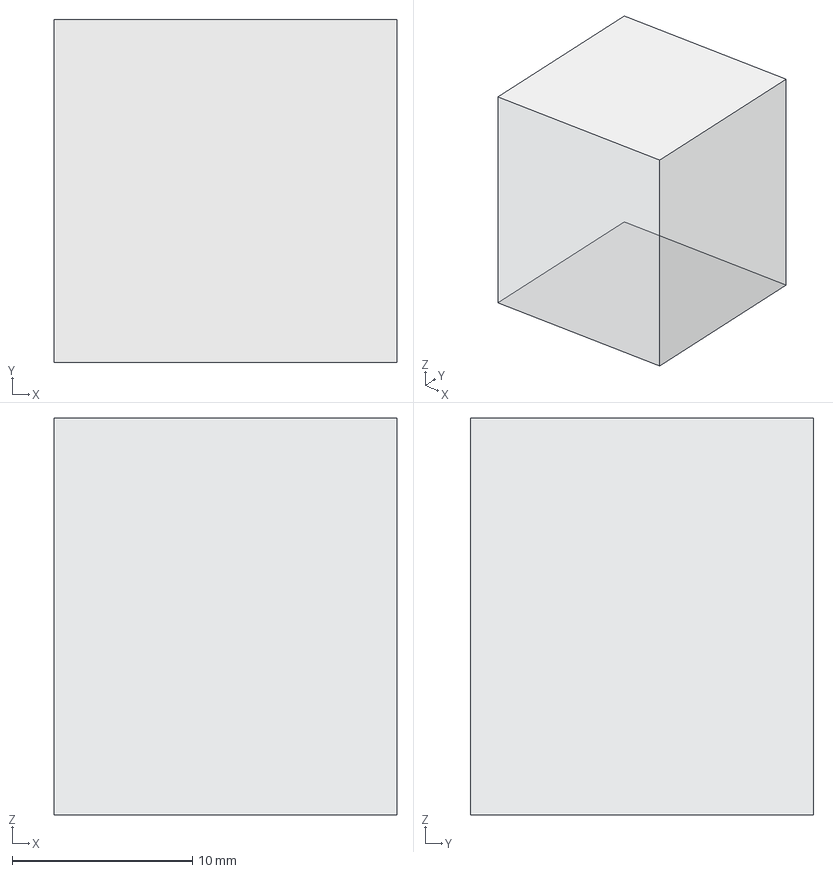
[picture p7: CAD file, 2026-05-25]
04_Implementation/DetectorAssembly/Manufacturing/STEP/01_ScintillationCrystalHolder/Crystal.step
19.0 x 19.0 x 22.0 mm

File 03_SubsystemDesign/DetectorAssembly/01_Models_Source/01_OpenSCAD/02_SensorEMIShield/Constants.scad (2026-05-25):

$fn = 100;

/*
Detector crystal pack

- 16 x LYSO bars, each 4 x 4 x 22 mm
- Arranged as a 4 x 4 matrix in X/Y
- 22 mm side is vertical (Z)
- Nominal bare crystal pack = 16 x 16 x 22 mm

PTFE reflector strategy
- 1 mm PTFE wraps the OUTER vertical side faces of the pack.
- 1 mm PTFE dividers are inserted BETWEEN the four 2x2 crystal sub-groups,
  i.e. one divider strip in X and one in Y, aligned with the gaps between
  adjacent SiPMs of the 2x2 SiPM array. This optically isolates each SiPM
  quadrant.
- The SiPM coupling face (bottom) is left free for optical gel.
*/

CRYSTALS_NUM_X = 4;
CRYSTALS_NUM_Y = 4;
LYSO_BAR_SIDE = 4;
LYSO_BAR_Z = 22;

// Bare crystal pack dimensions
CRYSTAL_X = LYSO_BAR_SIDE * CRYSTALS_NUM_X;   // 16 mm
CRYSTAL_Y = LYSO_BAR_SIDE * CRYSTALS_NUM_Y;   // 16 mm
CRYSTAL_Z = LYSO_BAR_Z;                       // 22 mm

// PTFE reflector wrap assumptions
// Outer wrap on the four vertical side faces.
PTFE_THICKNESS = 1.0;

// Internal PTFE dividers between SiPM sub-groups.
// The 4x4 crystal pack is split into a 2x2 grid of 2x2 crystal sub-groups,
// one sub-group per SiPM. A single PTFE strip of this thickness sits in the
// gap between adjacent sub-groups in X, and another in Y.
PTFE_INTERNAL_THICKNESS = 1.0;

// Number of internal PTFE dividers along each in-plane axis.
// 2 SiPMs per axis -> 1 divider per axis between the sub-groups.
SIPM_GROUPS_X = 2;
SIPM_GROUPS_Y = 2;
PTFE_INTERNAL_COUNT_X = SIPM_GROUPS_X - 1;   // 1
PTFE_INTERNAL_COUNT_Y = SIPM_GROUPS_Y - 1;   // 1

CAVITY_CLEARANCE_XY = 0.2;

// Wrapped envelope = bare crystals + outer PTFE wrap + internal PTFE dividers
WRAPPED_CRYSTAL_X = CRYSTAL_X
                    + 2 * PTFE_THICKNESS
                    + PTFE_INTERNAL_COUNT_X * PTFE_INTERNAL_THICKNESS;  // 19 mm
WRAPPED_CRYSTAL_Y = CRYSTAL_Y
                    + 2 * PTFE_THICKNESS
                    + PTFE_INTERNAL_COUNT_Y * PTFE_INTERNAL_THICKNESS;  // 19 mm
WRAPPED_CRYSTAL_Z = CRYSTAL_Z;                       // unchanged in this open-frame concept

// Holder wall thickness around cavity
HOLDER_THICKNESS = 2.5;

// Optical coupling stack between SiPM top and crystal bottom face
GEL_GAP = 0.1;

// SiPM geometry
SIPM_XY_SIDE = 7.2;        // package size
SIPM_ACTIVE_XY_SIDE = 6.0; // active area, centered within package
SIPM_Z_SIDE = 0.65;

// 2x2 SiPM matrix pitch
// Default assumes the packages are placed edge-to-edge.
SIPM_PITCH_X = SIPM_XY_SIDE;
SIPM_PITCH_Y = SIPM_XY_SIDE;

// Brass threaded insert assumptions (provisional, per prior approval)
// These are heat-set inserts for plastic, not blind rivets.
INSERT_THREAD = 2.5;
INSERT_OD = 3.5;
INSERT_LENGTH = 5.0;

// PROVISIONAL pilot-hole diameter.
// Final value must be replaced by the exact supplier datasheet recommendation.
INSERT_PILOT_D = 3.2;
INSERT_PILOT_DEPTH = INSERT_LENGTH + 0.3;
INSERT_LEADIN_D = 3.6;
INSERT_LEADIN_H = 1.0;

// Reinforcement around each insert
INSERT_BOSS_OD = 7.2;
INSERT_BOSS_HEIGHT = 6.0;

// Mounting layout
INSERT_SPACING_Y = 14.0;     // center-to-center spacing on each side flange
FLANGE_WIDTH = 10.0;         // outward from holder side
FLANGE_OVERHANG_Y = 3.5;     // flange extends beyond holder in +/-Y
FLANGE_EDGE_MARGIN_Y = 2.0;  // edge margin beyond boss envelope

// PTFE seam relief pocket inside cavity
PTFE_SEAM_RELIEF_WIDTH = 3.0;
PTFE_SEAM_RELIEF_DEPTH = 0.4;

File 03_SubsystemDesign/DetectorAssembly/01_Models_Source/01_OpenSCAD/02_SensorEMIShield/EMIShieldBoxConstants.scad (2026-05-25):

// =============================================================
// EMI shield enclosure - shared parameters
// =============================================================
//
// Concept
// - Single sheet-metal blank, laser/water-jet cut flat then bent.
// - 4 side walls fold DOWN from a top panel.
// - Each wall ends in an outward PCB mounting flange in the PCB plane.
// - Bottom (PCB side) is OPEN; PCB itself closes the shield.
// - Top panel has a 17 x 17 mm aperture for the scintillator/SiPM stack.
// - EMI continuity at corners: LEFT and RIGHT walls carry L-shaped
//   overlap tabs at both ends. When folded, those tabs bend 90 deg
//   inward and lap behind the inside face of the TOP and BOTTOM walls.
//
// Sign conventions for the assembled box
// - PCB top surface = z = 0
// - Box extends upward in +Z
// - Assembled outside footprint = TOP_X x TOP_Y, centered on origin
// - Assembled outside height above PCB = WALL_H
//
// Manufacturing notes (quote-level)
// - All geometry is mid-line / nominal.
// - Final blank MUST be adjusted by the fabricator for bend allowance,
//   bend deduction, K-factor, inside bend radius and tooling corner relief.

$fn = 80;

// -----------------------------
// Main parameters
// -----------------------------

// Outside footprint of the assembled box (= outer dimensions of the top panel).
TOP_X = 50;              // mm
TOP_Y = 50;              // mm

// Height of the box wall above the PCB.
WALL_H = 20;             // mm

// PCB mounting flange (folded outward at the bottom of each wall).
FLANGE_W = 8;            // mm

// Sheet thickness (also used as physical THICKNESS in the 3D preview
// AND as the in-plane offset between an overlap tab and the perpendicular
// wall it sits behind).
THICKNESS = 1.0;         // mm

// Top aperture for the scintillation crystal / SiPM optical path.
APERTURE_X = 17;         // mm
APERTURE_Y = 17;         // mm

// PCB mounting hole pattern.
MOUNT_HOLE_D = 2.8;      // mm  (M2.5 clearance, prototype)
// Distance of hole centers from each end of a flange, along the flange length.
HOLE_EDGE_MARGIN = 5.0;  // mm
// Default = 2 holes per flange (one near each end) = 8 holes total.

// -----------------------------
// EMI overlap-tab parameters
// -----------------------------

// L-shaped overlap tab on the left/right wall ends.
// In the flat blank the tab is an in-line extension of the wall plate;
// in the folded box it bends 90 deg inward at the wall corner and
// overlaps the inside face of the perpendicular (top/bottom) wall.
TAB_LEN = 5;             // mm, length of the inward fold

// Width of the laser kerf cut that separates a tab from the adjacent
// perpendicular strip in the FLAT pattern (so the tab becomes a free
// flap that can be bent independently).
TAB_KERF = 0.3;          // mm

// -----------------------------
// Derived values
// -----------------------------

STRIP_W  = WALL_H + FLANGE_W;     // each side strip: wall + flange
TOTAL_X  = TOP_X + 2 * STRIP_W;   // nominal developed blank width
TOTAL_Y  = TOP_Y + 2 * STRIP_W;   // nominal developed blank height

HALF_X = TOP_X / 2;
HALF_Y = TOP_Y / 2;

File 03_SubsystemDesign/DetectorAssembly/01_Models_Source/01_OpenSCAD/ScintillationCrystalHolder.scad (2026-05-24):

include <Constants.scad>;
include <SiPM.scad>;
include <ScintillationCrystal.scad>;

// Internal cavity sized for PTFE-wrapped crystal + assembly clearance
CAVITY_X = WRAPPED_CRYSTAL_X + 2 * CAVITY_CLEARANCE_XY;
CAVITY_Y = WRAPPED_CRYSTAL_Y + 2 * CAVITY_CLEARANCE_XY;
CAVITY_Z = WRAPPED_CRYSTAL_Z;

// Main holder frame outer dimensions
HOLDER_X = CAVITY_X + 2 * HOLDER_THICKNESS;
HOLDER_Y = CAVITY_Y + 2 * HOLDER_THICKNESS;
HOLDER_Z = CAVITY_Z;

// Holder sits above the PCB by the SiPM thickness + optical gel gap
HOLDER_Z_OFFSET = SIPM_Z_SIDE + GEL_GAP;

// Full height from PCB top plane (z = 0) to top of holder
MOUNT_TOTAL_Z = HOLDER_Z + HOLDER_Z_OFFSET;

// Continuous side flanges sized to safely carry two heat-set inserts per side
FLANGE_Y = max(
  HOLDER_Y + 2 * FLANGE_OVERHANG_Y,
  INSERT_SPACING_Y + INSERT_BOSS_OD + 2 * FLANGE_EDGE_MARGIN_Y
);

module cavity_cutout() {
  // Open-frame holder: cavity is open through the full Z height.
  cube([ CAVITY_X, CAVITY_Y, HOLDER_Z + 1 ], center = true);
}

module ptfe_seam_relief() {
  // Small local relief in one inner wall to accommodate PTFE seam overlap.
  translate([
    0,
    CAVITY_Y / 2 + PTFE_SEAM_RELIEF_DEPTH / 2,
    0
  ]) {
    cube([
      PTFE_SEAM_RELIEF_WIDTH,
      PTFE_SEAM_RELIEF_DEPTH,
      HOLDER_Z + 1
    ], center = true);
  }
}

module holder_frame() {
  difference() {
    cube([ HOLDER_X, HOLDER_Y, HOLDER_Z ], center = true);
    cavity_cutout();
    ptfe_seam_relief();
  }
}

module insert_pilot_hole() {
  // Bottom-installed heat-set insert cavity.
  // Pilot diameter is provisional and must be verified against supplier data.
  union() {
    translate([ 0, 0, INSERT_PILOT_DEPTH / 2 ])
      cylinder(d = INSERT_PILOT_D, h = INSERT_PILOT_DEPTH + 0.02, center = true);

    translate([ 0, 0, INSERT_LEADIN_H / 2 ])
      cylinder(d1 = INSERT_LEADIN_D, d2 = INSERT_PILOT_D, h = INSERT_LEADIN_H, center = true);
  }
}

module flange_insert_boss(x_pos, y_pos) {
  translate([ x_pos, y_pos, INSERT_BOSS_HEIGHT / 2 ])
    cylinder(d = INSERT_BOSS_OD, h = INSERT_BOSS_HEIGHT, center = true);
}

module side_flange(side = 1) {
  flange_x = side * (HOLDER_X / 2 + FLANGE_WIDTH / 2);

  difference() {
    union() {
      // Continuous flange running from PCB plane to top of holder
      translate([ flange_x, 0, MOUNT_TOTAL_Z / 2 ])
        cube([ FLANGE_WIDTH, FLANGE_Y, MOUNT_TOTAL_Z ], center = true);

      // Local reinforcement bosses for inserts
      for (y_pos = [ -INSERT_SPACING_Y / 2, INSERT_SPACING_Y / 2 ]) {
        flange_insert_boss(flange_x, y_pos);
      }
    }

    // Blind pilot holes opening from the PCB side (bottom)
    for (y_pos = [ -INSERT_SPACING_Y / 2, INSERT_SPACING_Y / 2 ]) {
      translate([ flange_x, y_pos, 0 ])
        insert_pilot_hole();
    }
  }
}

module mounting_flanges() {
  side_flange(-1);
  side_flange(1);
}

module scintillation_crystal_holder() {
  union() {
    translate([ 0, 0, HOLDER_Z_OFFSET + HOLDER_Z / 2 ])
      holder_frame();

    mounting_flanges();
  }
}

scintillation_crystal_holder();
//

// Optional debug view of the wrapped crystal envelope inside the holder:
// %translate([ 0, 0, HOLDER_Z_OFFSET + HOLDER_Z / 2 ])
//   wrapped_scintillation_crystal_envelope();
// sipm_array();

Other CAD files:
03_SubsystemDesign/DetectorAssembly/01_Models_Source/01_OpenSCAD/01_ScintillationCrystalHolder/Main.scad
03_SubsystemDesign/DetectorAssembly/01_Models_Source/01_OpenSCAD/01_ScintillationCrystalHolder/ScintillationCrystal.scad
03_SubsystemDesign/DetectorAssembly/01_Models_Source/01_OpenSCAD/01_ScintillationCrystalHolder/ScintillationCrystalHolder.scad
03_SubsystemDesign/DetectorAssembly/01_Models_Source/01_OpenSCAD/01_ScintillationCrystalHolder/SiPM.scad
03_SubsystemDesign/DetectorAssembly/01_Models_Source/01_OpenSCAD/02_SensorEMIShield/EMIShieldBox2D.scad
03_SubsystemDesign/DetectorAssembly/01_Models_Source/01_OpenSCAD/02_SensorEMIShield/EMIShieldBox3D.scad
03_SubsystemDesign/DetectorAssembly/01_Models_Source/01_OpenSCAD/02_SensorEMIShield/EMIShieldBoxParts.scad
03_SubsystemDesign/DetectorAssembly/02_Models_COTS/MICROFC-60035-SMT-TR1.stl

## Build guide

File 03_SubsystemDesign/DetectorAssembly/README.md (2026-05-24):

# Purpose

The 3D printed holder needs to:
* Attach the grid of scintillator crystals to the PCB in a way that maximizes surface contact with the SiPM detectors
* Attach reflection pads to the sides of the scintillator crystals to maximize photons deposited on the SiPMs
* Provide space for optical gel between the scintillator crystals and the SiPMs
* Make no obstruction to mounting a Peltier-based cooling module on the opposite side of the PCB

# Tools

* ***OpenSCAD*** for creating 3D models (model-as-code, easy for version control).
* ***FreeCAD*** for adding rivets and final inspection before printing (it has the "measure" tool to verify dimensions, which OpenSCAD lacks).

M2.5(OD 3.5mm)50pcs

https://pl.aliexpress.com/item/1005007640664497.html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

PTFE 1mm thicknes
https://pl.aliexpress.com/item/1005011914032387.html

Left side: (-19.7, -6) and (-19.7, +6)
Right side: (+19.7, -6) and (+19.7, +6)
12.0 mm
39.4 mm

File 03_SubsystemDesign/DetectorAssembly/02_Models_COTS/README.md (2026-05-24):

# Purpose

Commercial Off‑The‑Shelf (COTS) models.

Note: Models in this folder are not to be modified.

# Origins

The file MICROFC-60035-SMT-TR1.stp was downloaded from:
https://fr.farnell.com/en-FR/on-semiconductor/microfc-60035-smt-tr1/sipm-ic-35um-cwdfn-4/dp/2949095

Although it is possible to download the STL format, it fails to open in OpenSCAD. 
The STP file was manually converted to an STL file using FreeCAD.

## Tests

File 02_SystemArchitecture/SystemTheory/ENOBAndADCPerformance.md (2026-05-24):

# ENOB and ADC Performance Limitations

## 1. Purpose
This document defines the relationship between nominal ADC resolution ($N$ bits), intrinsic ADC SNR, and achievable system ENOB. It establishes why system requirements must be derived from real ADC performance rather than ideal quantization assumptions.

---

## 2. Definitions

### 2.1 Ideal Quantization SNR
For an ideal $N$-bit ADC:

$$SNR_{ideal} = 6.02N + 1.76 \text{ dB}$$

This represents the theoretical limit assuming quantization noise is the only error source.

---

### 2.2 Correct Engineering Approach
The system ENOB must satisfy:

$$ENOB_{system} \le ENOB_{ADC}$$

A practical requirement must include a margin ($\Delta$):

$$ENOB_{system} \ge ENOB_{ADC} - \Delta$$

Where $\Delta$ is typically $0.2$ to $0.5$ bits to account for:
* Analog front-end noise
* Bandwidth limitations
* Clock jitter
* Anti-alias filtering
* Implementation/thermal variation

---

### 2.3 Deriving Noise Requirement from ENOB
Given a target ENOB, we find the required SNR:

$$SNR = 6.02 \cdot ENOB + 1.76$$

Using the relationship to RMS voltage:

$$SNR = 20 \log_{10} \left( \frac{V_{signal,rms}}{V_{noise,rms}} \right)$$

Solving for the allowable noise floor ($V_{noise,max}$):

$$V_{noise,max} = \frac{V_{signal,rms}}{10^{SNR/20}}$$

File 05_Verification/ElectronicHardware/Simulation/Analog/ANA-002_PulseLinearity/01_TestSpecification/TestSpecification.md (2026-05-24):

# ANA-002 Pulse Linearity Test Specification

## 1. Purpose

This document defines the verification procedure for requirement ANA-002:

"The analog front-end (AFE) shall exhibit integral non-linearity (INL) not exceeding 0.1 percent of full-scale over the differential output range from 0 V to 2.0 Vpp."

This test verifies dynamic pulse amplitude linearity of the AFE using transient simulation.

---

## 2. Scope

This test applies to:

- Complete analog front-end (CSA plus differential stage)
- Differential output at ADC input pins
- Nominal operating conditions

This test does not evaluate:

- Noise performance (covered by ANA-001)
- Dynamic range headroom (covered by ANA-003)
- Bandwidth (covered by ANA-004)
- Transient settling behavior (covered by ANA-005)

---

## 3. Definitions

Full-scale voltage (FS):

Differential ADC full-scale input range = 2.0 Vpp

Peak full-scale amplitude:

$$
V_{FS,peak} = \frac{2.0}{2} = 1.0 \text{ V}
$$

Integral Non-Linearity (INL):

Maximum deviation of measured output amplitude from best-fit linear regression line, normalized to full-scale peak amplitude.

$$
INL_{percent} = \frac{V_{measured} - V_{fit}}{V_{FS,peak}} \times 100
$$

---

## 4. Test Configuration

### 4.1 Simulation Model

- Charge Sensitive Amplifier topology
- Differential output stage
- SiPM input modeled as exponential current pulse

### 4.2 Stimulus

Input current pulse:

$$
I(t) = I_{amp} \cdot e^{-(t - t_0)/\tau_{scint}} \quad \text{for } t > t_0
$$

Where:

- $$ \tau_{scint} = 230 \text{ ns} $$
- $$ I_{amp} $$ is stepped to cover 0 to full-scale output

The sweep must include:

- Near-zero amplitude
- Amplitude sufficient to produce approximately 1.0 V peak differential output

---

## 5. Test Procedure

### Step 1 - DC Operating Point Validation

Verify:

- Differential baseline near 0 V
- Common-mode near VREF
- No saturation at nominal bias

If invalid, abort linearity evaluation.

---

### Step 2 - Sweep Coverage Validation

Measure:

- Minimum differential peak output
- Maximum differential peak output

Verify:

$$
V_{min} \approx 0
$$

$$
V_{max} \approx V_{FS,peak}
$$

The sweep must cover near 0 to near full-scale.

If sweep does not span near 0 to near FS, test is invalid.

---

### Step 3 - Peak Extraction

For each sweep step:

Compute differential output:

$$
V_{diff} = V(out\_p) - V(out\_n)
$$

Subtract baseline and extract peak absolute amplitude.

---

### Step 4 - Best-Fit Linear Regression

Perform first-order linear regression:

$$
V_{fit} = a \cdot I + b
$$

Using only points within the full-scale region.

---

### Step 5 - INL Calculation

For each valid point:

$$
INL_{volts} = V_{measured} - V_{fit}
$$

Normalize:

$$
INL_{percent} = \frac{INL_{volts}}{V_{FS,peak}} \times 100
$$

Determine:

$$
INL_{max} = \max(|INL_{percent}|)
$$

---

## 6. Acceptance Criteria

Requirement:

$$
INL_{max} \le 0.1 \text{ percent}
$$

Pass condition:

- DC operating point valid
- Sweep covers near 0 to near full-scale
- $$ INL_{max} \le 0.1 \text{ percent} $$

Fail condition:

- Any of the above criteria not met

---

## 7. Outputs

The verification shall produce:

- Differential output vs input current plot
- INL vs input current plot
- Numerical report of:
  - Maximum INL (percent FS)
  - Maximum INL (volts)
  - Maximum INL (LSB)
- Final PASS or FAIL verdict

All plots shall be archived as SVG artifacts.

---

## 8. Assumptions

- Nominal temperature
- Nominal supply voltage
- Nominal detector capacitance
- Pulse shape defined by $$ \tau_{scint} = 230 \text{ ns} $$
- No clipping or saturation within evaluated region

---

## 9. Traceability

Requirement ID: ANA-002  
Verification Method: Transient simulation  
Artifacts:
- ANA-002_PulseLinearity_OutputVsInput.svg
- ANA-PulseLinearity_INLPercentFS.svg

---

## 10. Notes

This test verifies dynamic pulse amplitude linearity only.

Gain magnitude accuracy and dynamic range margins are evaluated under separate requirements.

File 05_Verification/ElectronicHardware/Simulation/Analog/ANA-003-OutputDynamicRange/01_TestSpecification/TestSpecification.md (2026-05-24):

# ANA-003 Output Dynamic Range Test Specification

## 1. Purpose

This document defines the verification procedure for requirement ANA-003:

"The analog front-end (AFE) shall provide sufficient differential output
headroom to ensure linear operation within the specified detector input
current range, without clipping or excessive gain compression."

This test verifies dynamic range margin, ADC utilization, clipping behavior,
and gain compression characteristics of the AFE.

---

## 2. Scope

This test applies to:

- Complete analog front-end (CSA plus differential stage)
- Differential output at ADC input pins
- Maximum specified detector current range
- Nominal operating conditions

This test does not evaluate:

- Linearity over full-scale range (ANA-002)
- Noise performance (ANA-001)
- Small-signal bandwidth (ANA-004)
- Transient settling metrics (ANA-005)

---

## 3. Definitions

ADC full-scale differential input range:

$$
V_{FS,pp} = 2.0 \text{ V}
$$

Peak full-scale amplitude:

$$
V_{FS,peak} = \frac{V_{FS,pp}}{2} = 1.0 \text{ V}
$$

ADC utilization:

$$
Utilization_{percent} = \frac{V_{peak}}{V_{FS,peak}} \times 100
$$

Gain compression:

$$
Gain_{compression,percent} =
\frac{G_{low} - G_{high}}{G_{low}} \times 100
$$

Where:

- $$ G_{low} $$ is slope measured in linear region
- $$ G_{high} $$ is slope measured near maximum detector current

Clipping:

Output waveform exceeding the linear operating region,
or reaching supply limits.

---

## 4. Test Configuration

### 4.1 Simulation Model

- Charge Sensitive Amplifier topology
- Differential output stage
- SiPM input modeled as exponential current pulse
- Maximum detector current defined in configuration

### 4.2 Stimulus

Input current pulse:

$$
I(t) = I_{amp} \cdot e^{-(t - t_0)/\tau}
$$

Where:

- $$ I_{amp} $$ is stepped from small amplitude up to and beyond
  maximum specified detector current
- $$ \tau $$ is scintillator decay constant

Sweep must include:

- Nominal operating range
- Maximum specified detector current
- Slightly beyond nominal to verify headroom

---

## 5. Test Procedure

### Step 1 - Baseline Verification

Verify:

- Differential output centered correctly
- No premature saturation at nominal input levels

Abort if DC operating point invalid.

---

### Step 2 - Maximum Output Swing

Measure maximum differential output peak:

$$
V_{max,peak}
$$

Compute differential peak-to-peak swing:

$$
V_{max,pp} = 2 \cdot V_{max,peak}
$$

Verify:

$$
V_{max,pp} \ge 2.4 \text{ V}
$$

---

### Step 3 - ADC Utilization at Maximum Detector Current

At maximum specified detector current:

$$
Utilization_{percent} =
\frac{V_{peak}}{V_{FS,peak}} \times 100
$$

Verify:

$$
70 \le Utilization_{percent} \le 95
$$

---

### Step 4 - Gain Compression Evaluation

1. Perform linear regression in mid-scale region to obtain:

   $$ G_{low} $$

2. Perform local slope estimation near maximum detector current to obtain:

   $$ G_{high} $$

3. Compute:

   $$ Gain_{compression,percent} $$

Verify:

$$
Gain_{compression,percent} \le 1.0
$$

---

### Step 5 - Clipping Check

Verify that within the specified detector input range:

- No waveform clipping occurs
- No saturation is observed
- Output does not flatten or abruptly limit

If clipping occurs within specified range, requirement fails.

---

## 6. Acceptance Criteria

The requirement is satisfied if all conditions below are met:

1. $$ V_{max,pp} \ge 2.4 \text{ V} $$
2. $$ 70 \le Utilization_{percent} \le 95 $$
3. $$ Gain_{compression,percent} \le 1.0 $$
4. No clipping within specified detector current range

---

## 7. Outputs

The verification shall produce:

- Differential output vs input current plot
- ADC utilization calculation
- Gain compression calculation
- Statement confirming absence of clipping
- Final PASS or FAIL verdict

All plots shall be archived as SVG artifacts.

---

## 8. Assumptions

- Nominal temperature
- Nominal supply voltage
- Nominal detector capacitance
- Maximum detector current defined in configuration
- Linearity verified separately under ANA-002

---

## 9. Traceability

Requirement ID: ANA-003  
Verification Method: Transient simulation  
Artifacts:
- ANA003_OutputVsInput.svg
- ANA003_ADCUtilizationReport.txt
- ANA003_GainCompressionReport.txt

---

## 10. Notes

This requirement verifies operating headroom and dynamic range margin.
It does not evaluate linearity over full-scale range.
Linearity is covered by ANA-002.

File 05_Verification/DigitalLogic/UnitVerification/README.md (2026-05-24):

# Testbench

This directory contains VHDL testbench sources used for design verification.

> **Note:** Files in this directory are for simulation only and are not synthesizable.

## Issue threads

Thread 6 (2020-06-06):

Choose the best option for polarization of photomultiplier lamp.

RobertGawron, 2020-06-06:
There are at least two options:
- simple resistor divider
- usage of transistors in divider

Purpose of putting capacitors in parallel to resistors in last dynodes is unclear.

RobertGawron, 2020-10-31:
"simple resistor divider" will be used.

Closed 2020-10-31.

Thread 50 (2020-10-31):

Chose correct PCB outlines based on mechanical overview.

RobertGawron, 2020-10-31:
Place needs to be added around places where chassis is mounted to 3D printed holders, so that it's possible to remove PCB from chassis without disassembly of the whole device.

Closed 2020-11-08.

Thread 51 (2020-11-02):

Split existing circuit board after mechanical overview design

RobertGawron, 2020-11-02:
At least three PCBs are needed:

- polarization of the tube (easiest)
- HV generator board
- data acquisition

Git branch TBD.

RobertGawron, 2020-11-05:
Done in 15153827af57849d0052124f4810f018b86243d6

Closed 2020-11-05.

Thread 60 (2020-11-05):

Add current measurement of the HV power supply, if it's too high, for safety reason turn the supply down.

RobertGawron, 2020-11-05:

Closed 2020-11-06.

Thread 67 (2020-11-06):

Choose op-amp for hv power supply board

RobertGawron, 2020-11-06:
- low input bias currents
- low low noise

Closed 2020-11-07.

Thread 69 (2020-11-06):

Calculate how much power will be dissipated by HV power supply

RobertGawron, 2020-11-06:
This is important because it will be in a closed enclosure.

I'm sure, I will calculate it wrong :-D

RobertGawron, 2020-11-14:
Blocked by #91.

RobertGawron, 2020-11-17:
Done in 9fe8c6023c73f1af3155f958b007d8678d3d67fe

total_power_consumption: 1.571e-01 W

Closed 2020-11-17.

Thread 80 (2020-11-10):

Find minimum functionality level to provide data acquisition functionality.

RobertGawron, 2020-11-10:
There's a lot of papers online and I don't know a lot of things, but a simple and working version should be chosen.

With this, explore more things.

Note: PCB area is huge, there's space for two design in parallel

RobertGawron, 2020-11-23:
Current version seams to be ok.

Closed 2020-11-23.

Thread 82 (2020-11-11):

Add RC filter to cut-off noise from LT3580 switching frequency

RobertGawron, 2020-11-11:
In configuration with resistor dividers polarizing PHT, -just in case- add mentioned RC filter,

RobertGawron, 2020-11-14:
Blocked by #91.

RobertGawron, 2020-11-17:
Done in 9fe8c6023c73f1af3155f958b007d8678d3d67fe

Closed 2020-11-17.

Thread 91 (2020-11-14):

After review, it seems that HV power supply is broken by design, make a new circuit.

RobertGawron, 2020-11-14:
Life is life.

RobertGawron, 2020-11-17:
Draft done in 9fe8c6023c73f1af3155f958b007d8678d3d67fe

RobertGawron, 2020-11-22:
Done in 9fe8c60

Closed 2020-11-22.

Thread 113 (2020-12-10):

Apply changes after third HW rewiew.

RobertGawron, 2020-12-10:
Chosen PMT needs 1k5V, much more than originally planed, using cascode with transistors in series seems to be a bad idea.

Use shunt voltage regulator for first winding of transformer, this will keep regulator-transistor voltage small. High voltage wil be build by connecting transformers winding in series. This will also solve problem with finding diodes with sufficient reverse voltage.

Closed 2024-09-15.

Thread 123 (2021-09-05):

Abandon -so horrible- UmbrellaUML tool and switch to PlantUML, also rework all diagrams

RobertGawron, 2021-09-05:
Remove associations to Raspberry, since it might be any other client, remove part with GUI, recheck amount of sensors.

Closed 2024-09-15.

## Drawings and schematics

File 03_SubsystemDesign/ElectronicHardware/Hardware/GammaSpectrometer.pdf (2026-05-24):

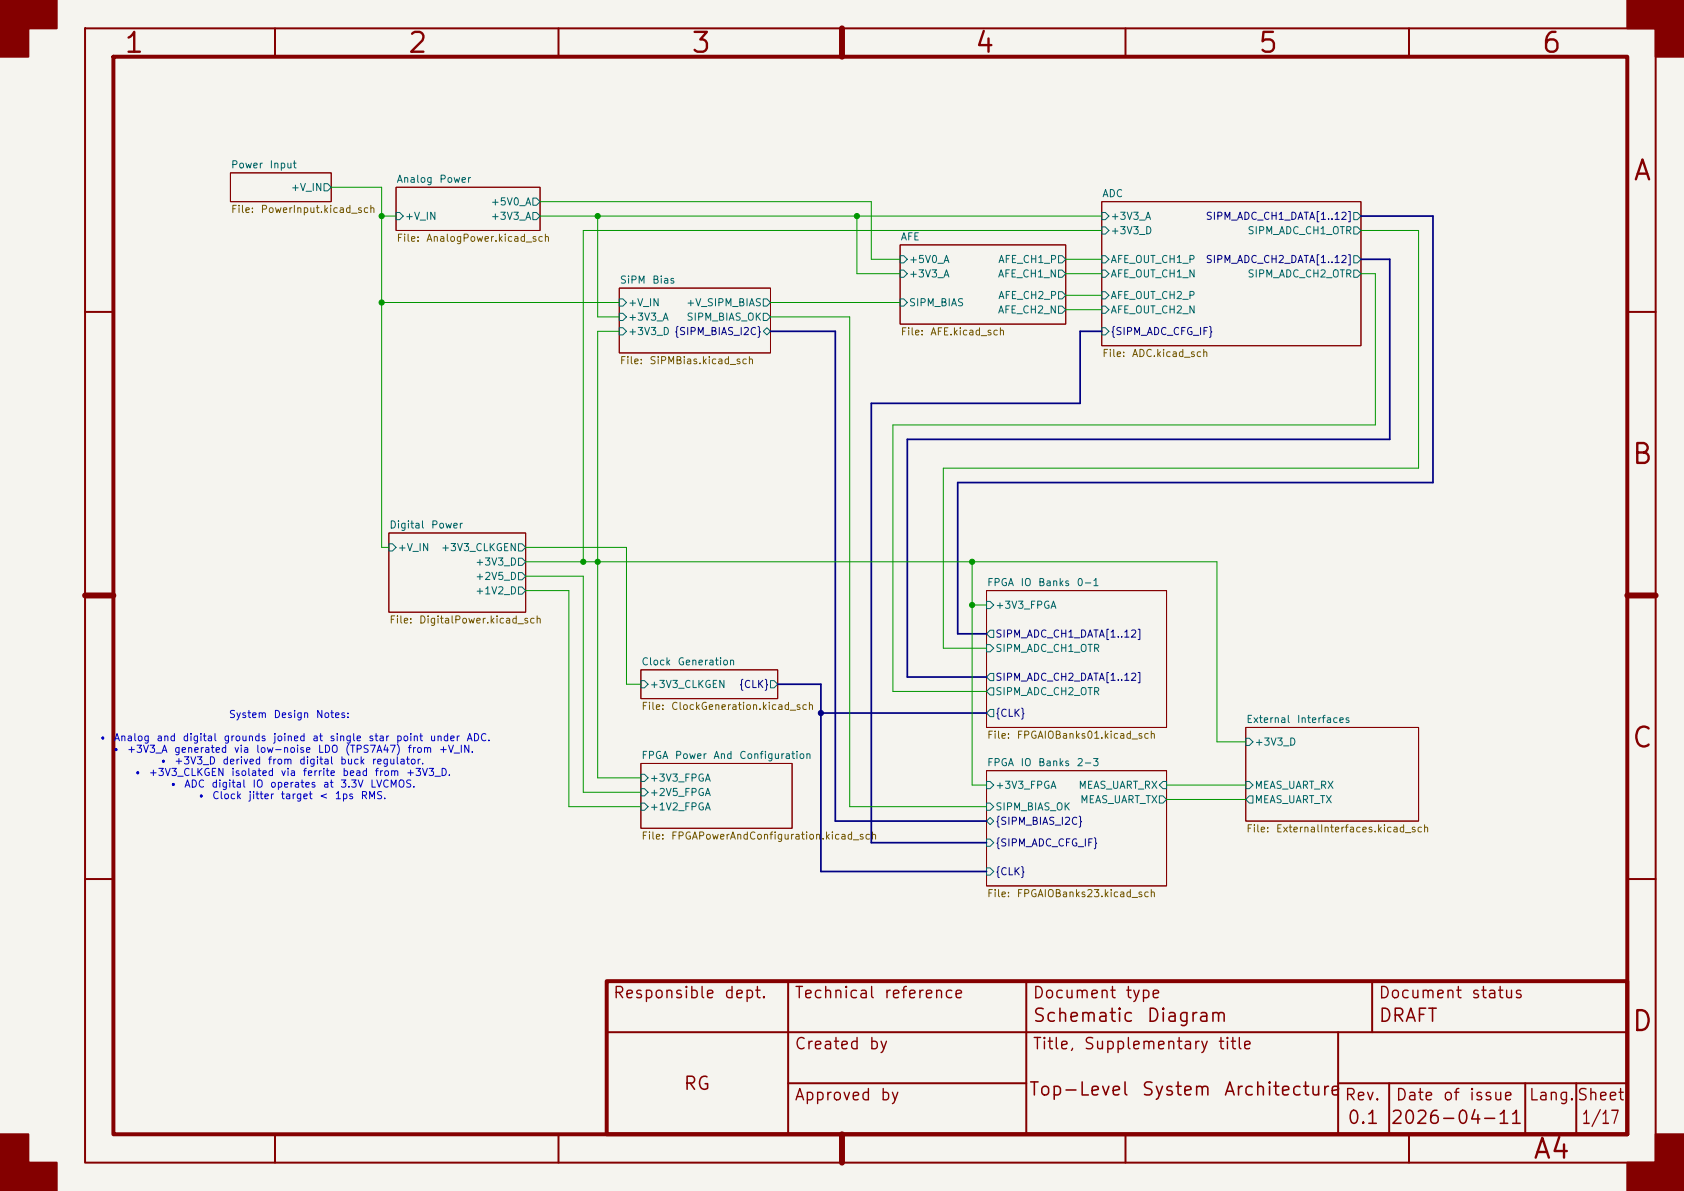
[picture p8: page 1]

Analog Power File: AnalogPower.kicad_sch +V_IN

{CLK} FPGA IO Banks 0-1

File: FPGAPowerAndConfiguration.kicad_sch +3V3_CLKGEN {CLK} Clock Generation

File: FPGAIOBanks01.kicad_sch System Design Notes: • Analog and digital grounds joined at single star point under ADC. • +3V3_A generated via low-noise LDO (TPS7A47) from +V_IN. • +3V3_D derived from digital buck regulator. • +3V3_CLKGEN isolated via ferrite bead from +3V3_D. • ADC digital IO operates at 3.3V LVCMOS. • Clock jitter target < 1ps RMS.

FPGA Power And Configuration

Responsible dept. | Technical reference | Document type Schematic Diagram | Document status DRAFT

Created by | Title, Supplementary title Top-Level System Architecture

Approved by | | 0.1 | 2026-04-11 | 1/17

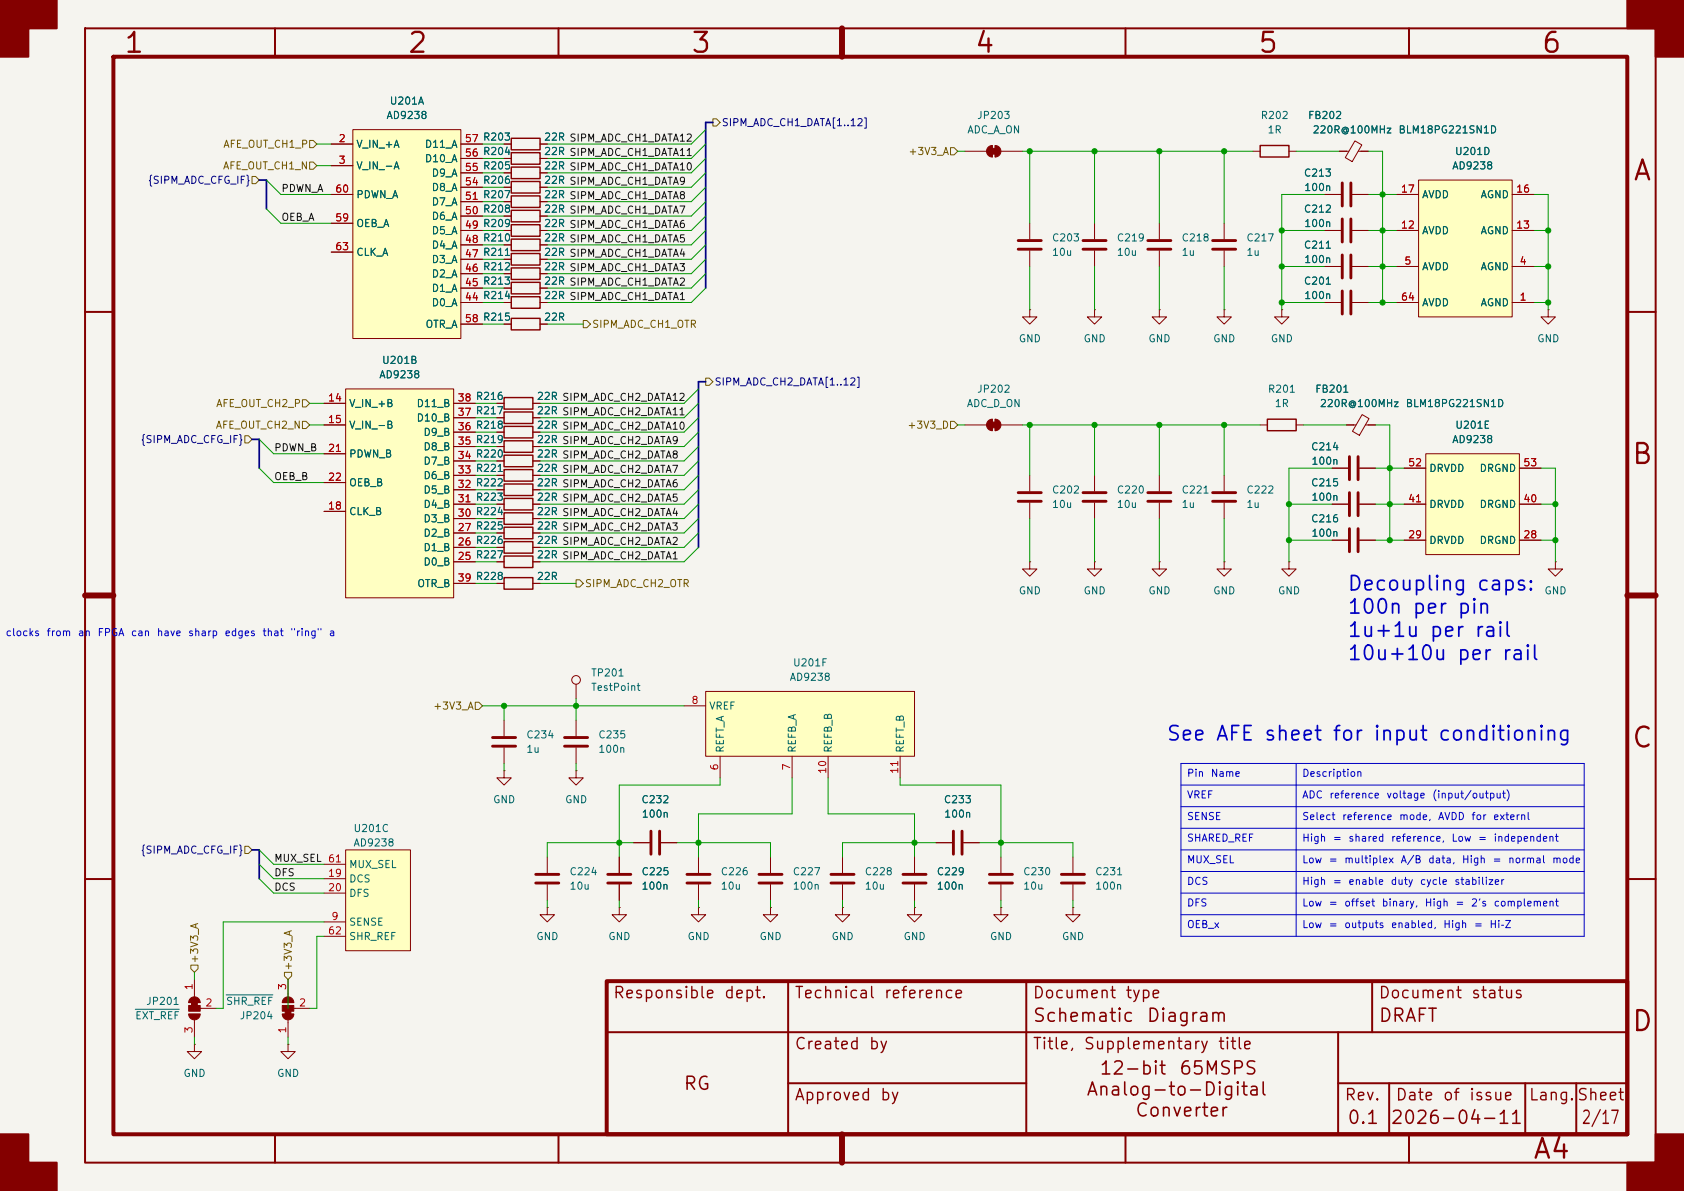
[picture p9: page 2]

See AFE sheet for input conditioning

Responsible dept. | Technical reference | Document type Schematic Diagram | Document status DRAFT

Created by | Title, Supplementary title 12-bit 65MSPS Analog-to-Digital Converter

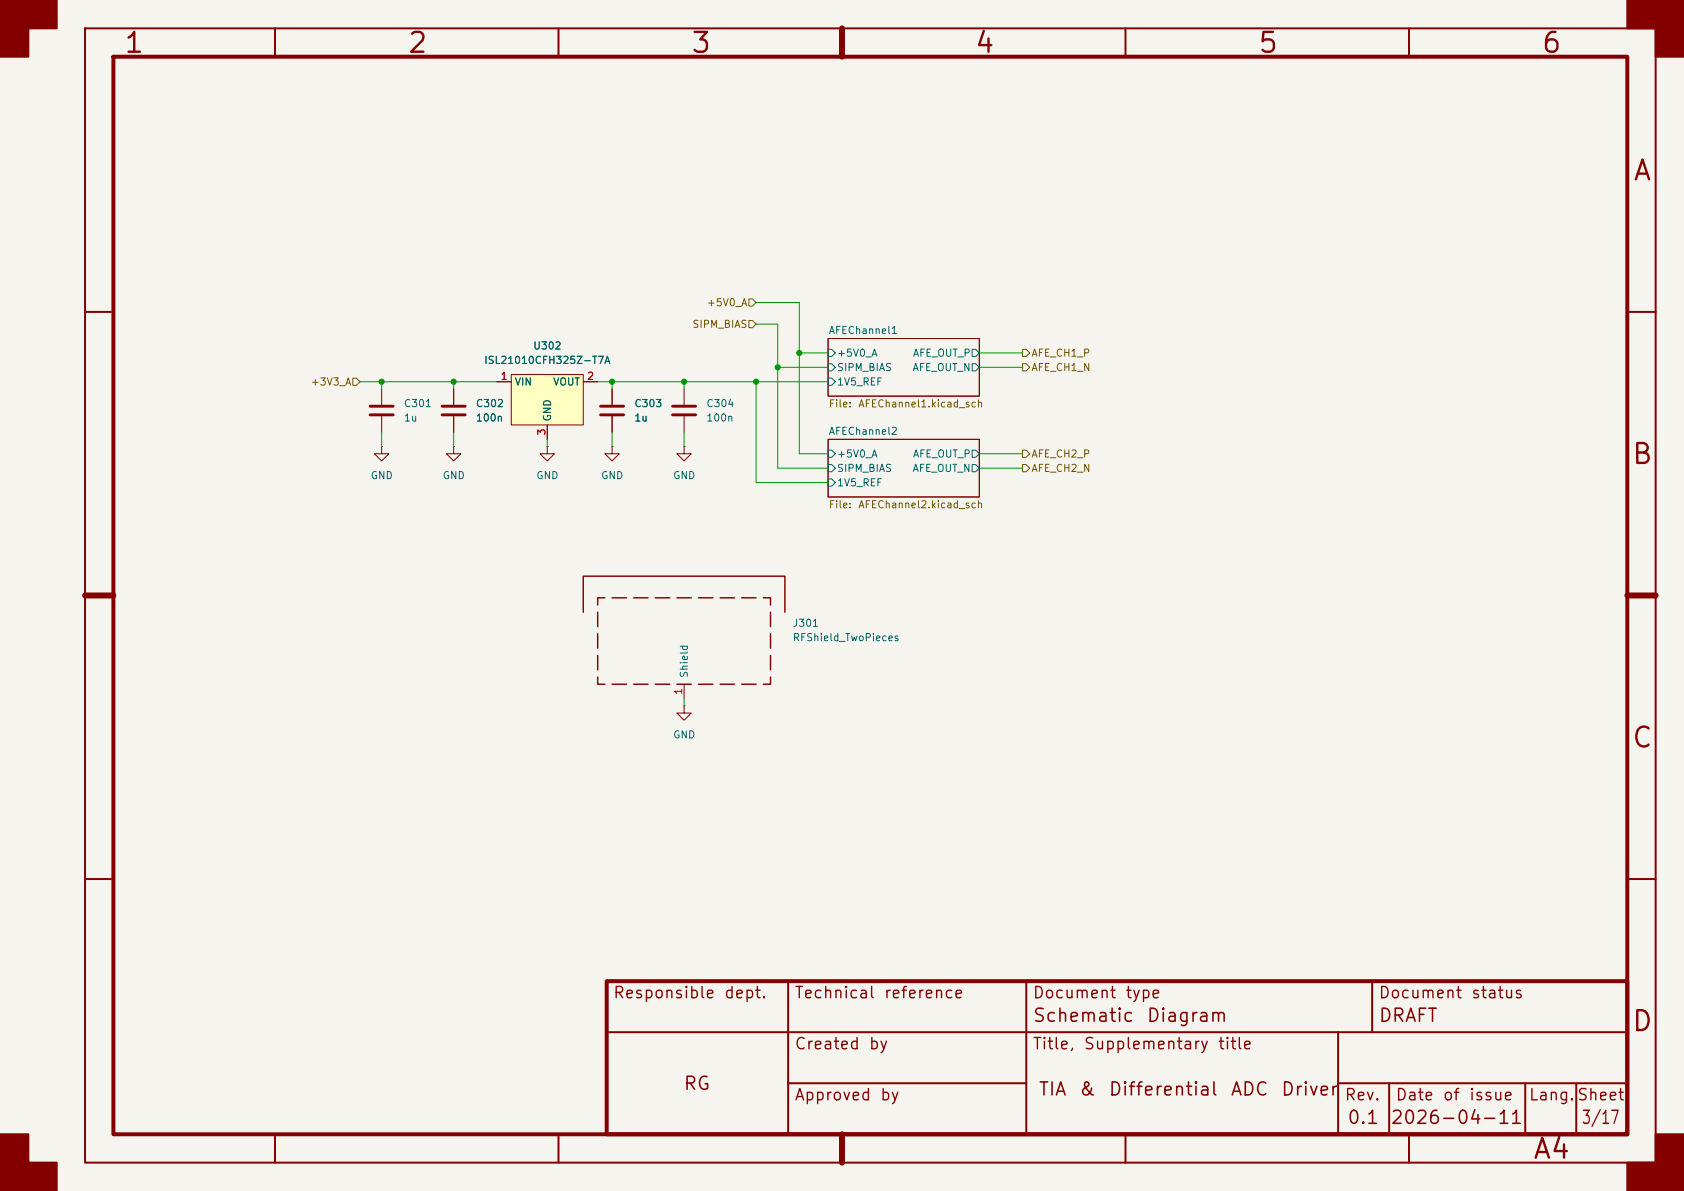
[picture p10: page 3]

Responsible dept. | Technical reference | Document type Schematic Diagram | Document status DRAFT

Created by | Title, Supplementary title TIA & Differential ADC Driver

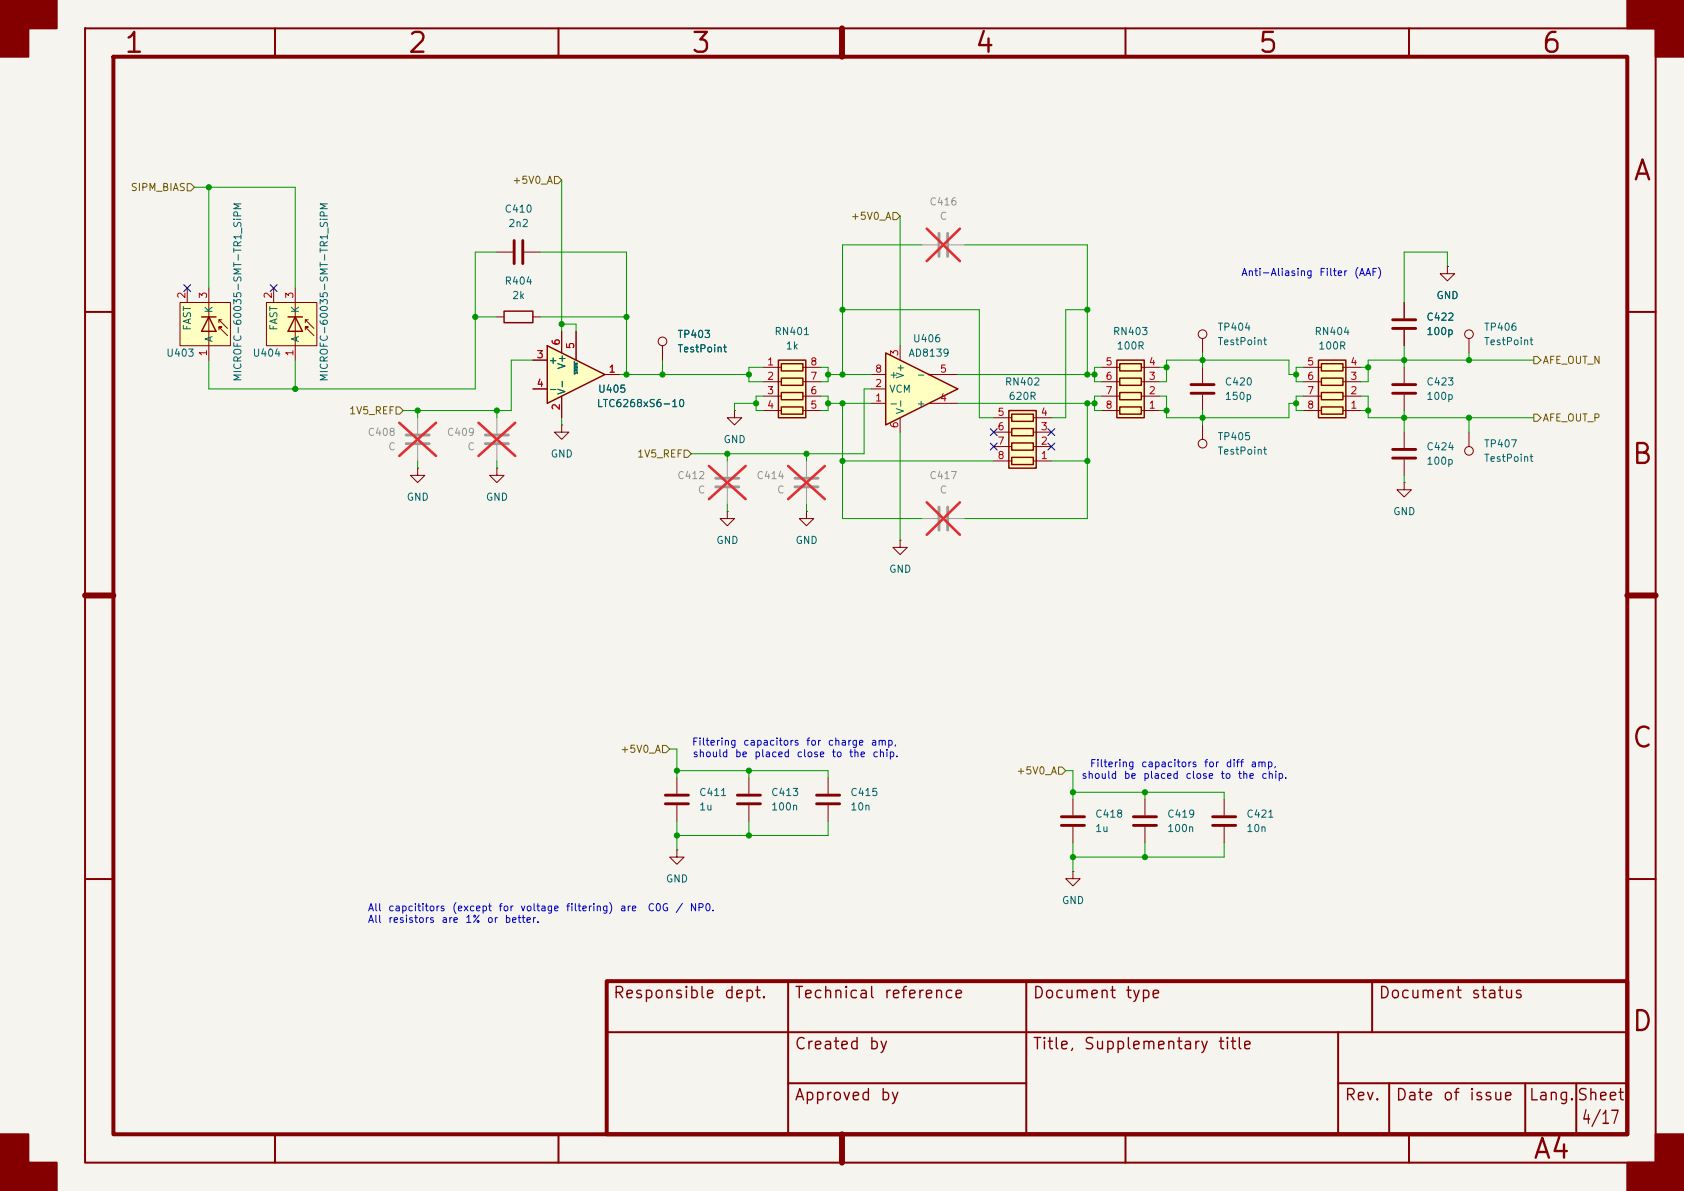
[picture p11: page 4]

Anti-Aliasing Filter (AAF)

Responsible dept. | Technical reference | Document type | Document status

Created by | Title, Supplementary title

Rev. | Date of issue | Lang. Sheet | 4/17

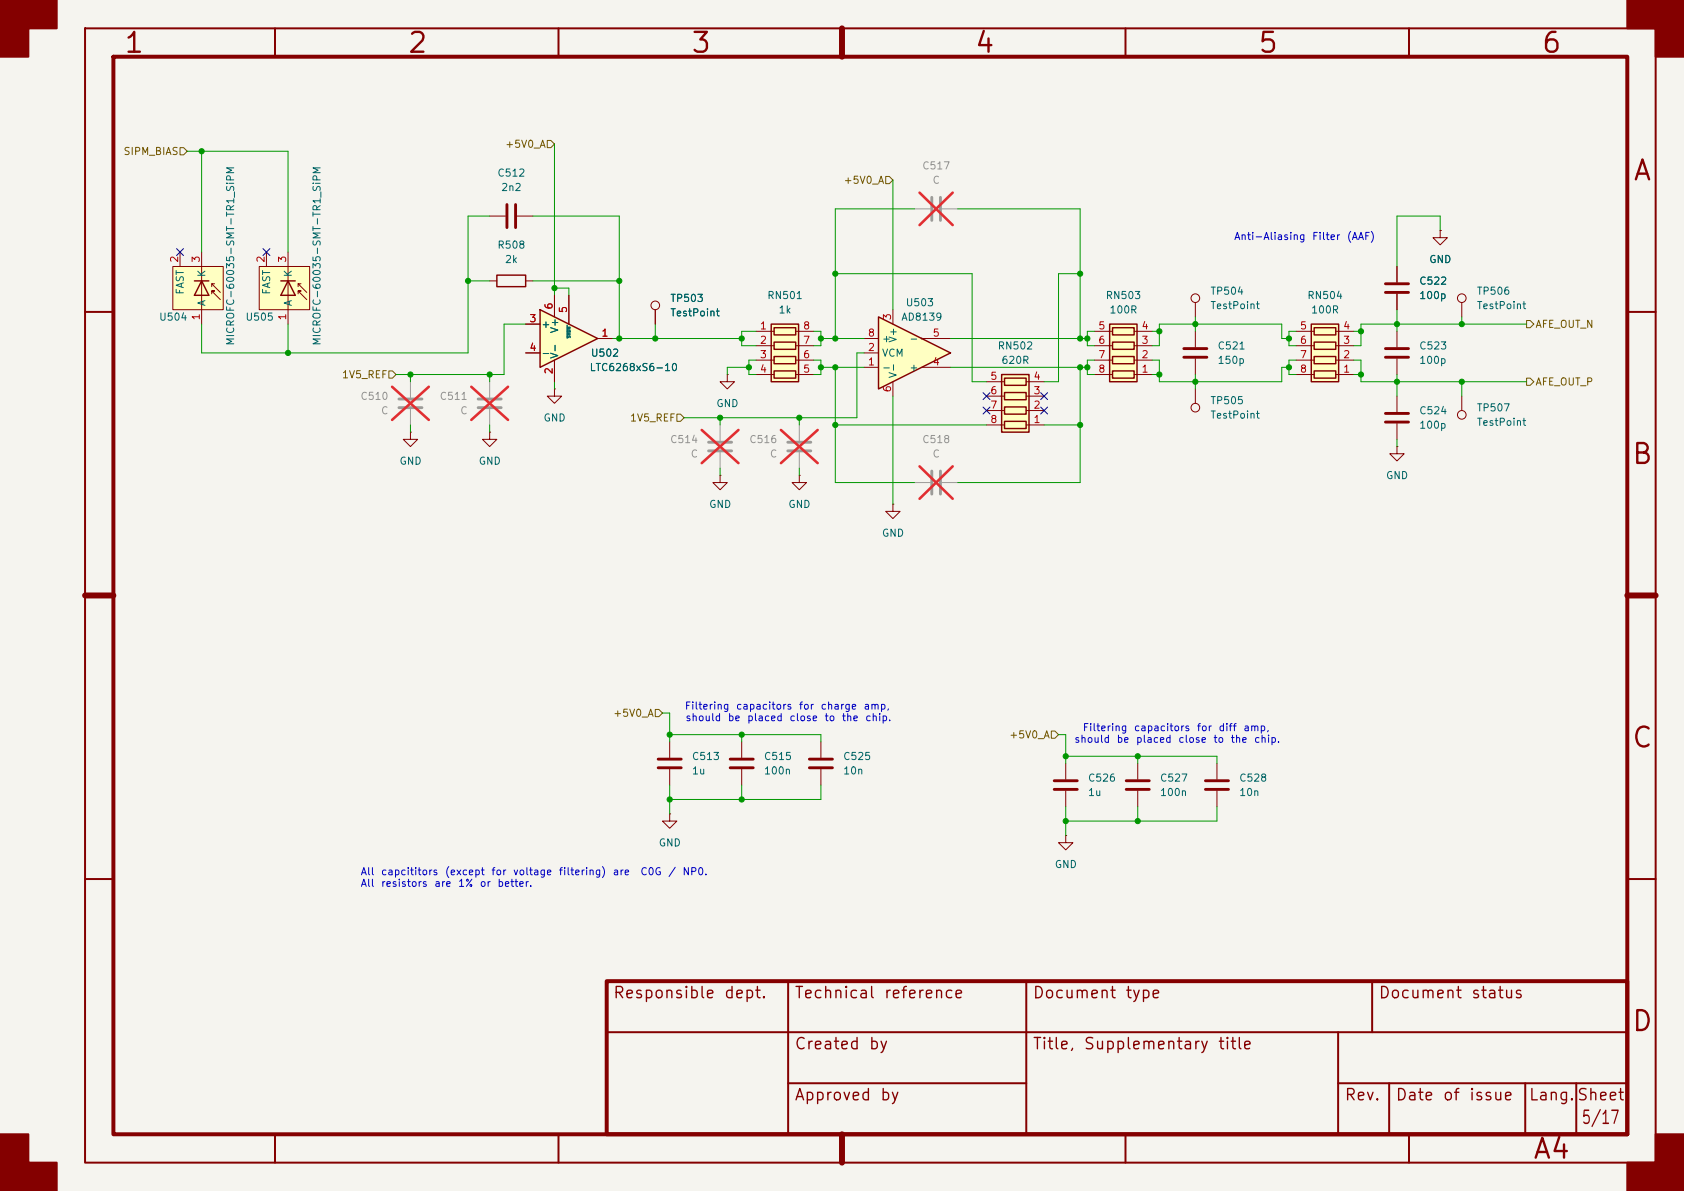
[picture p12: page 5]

Responsible dept. | Technical reference | Document type | Document status

Created by | Title, Supplementary title

Rev. | Date of issue | Lang. Sheet | 5/17

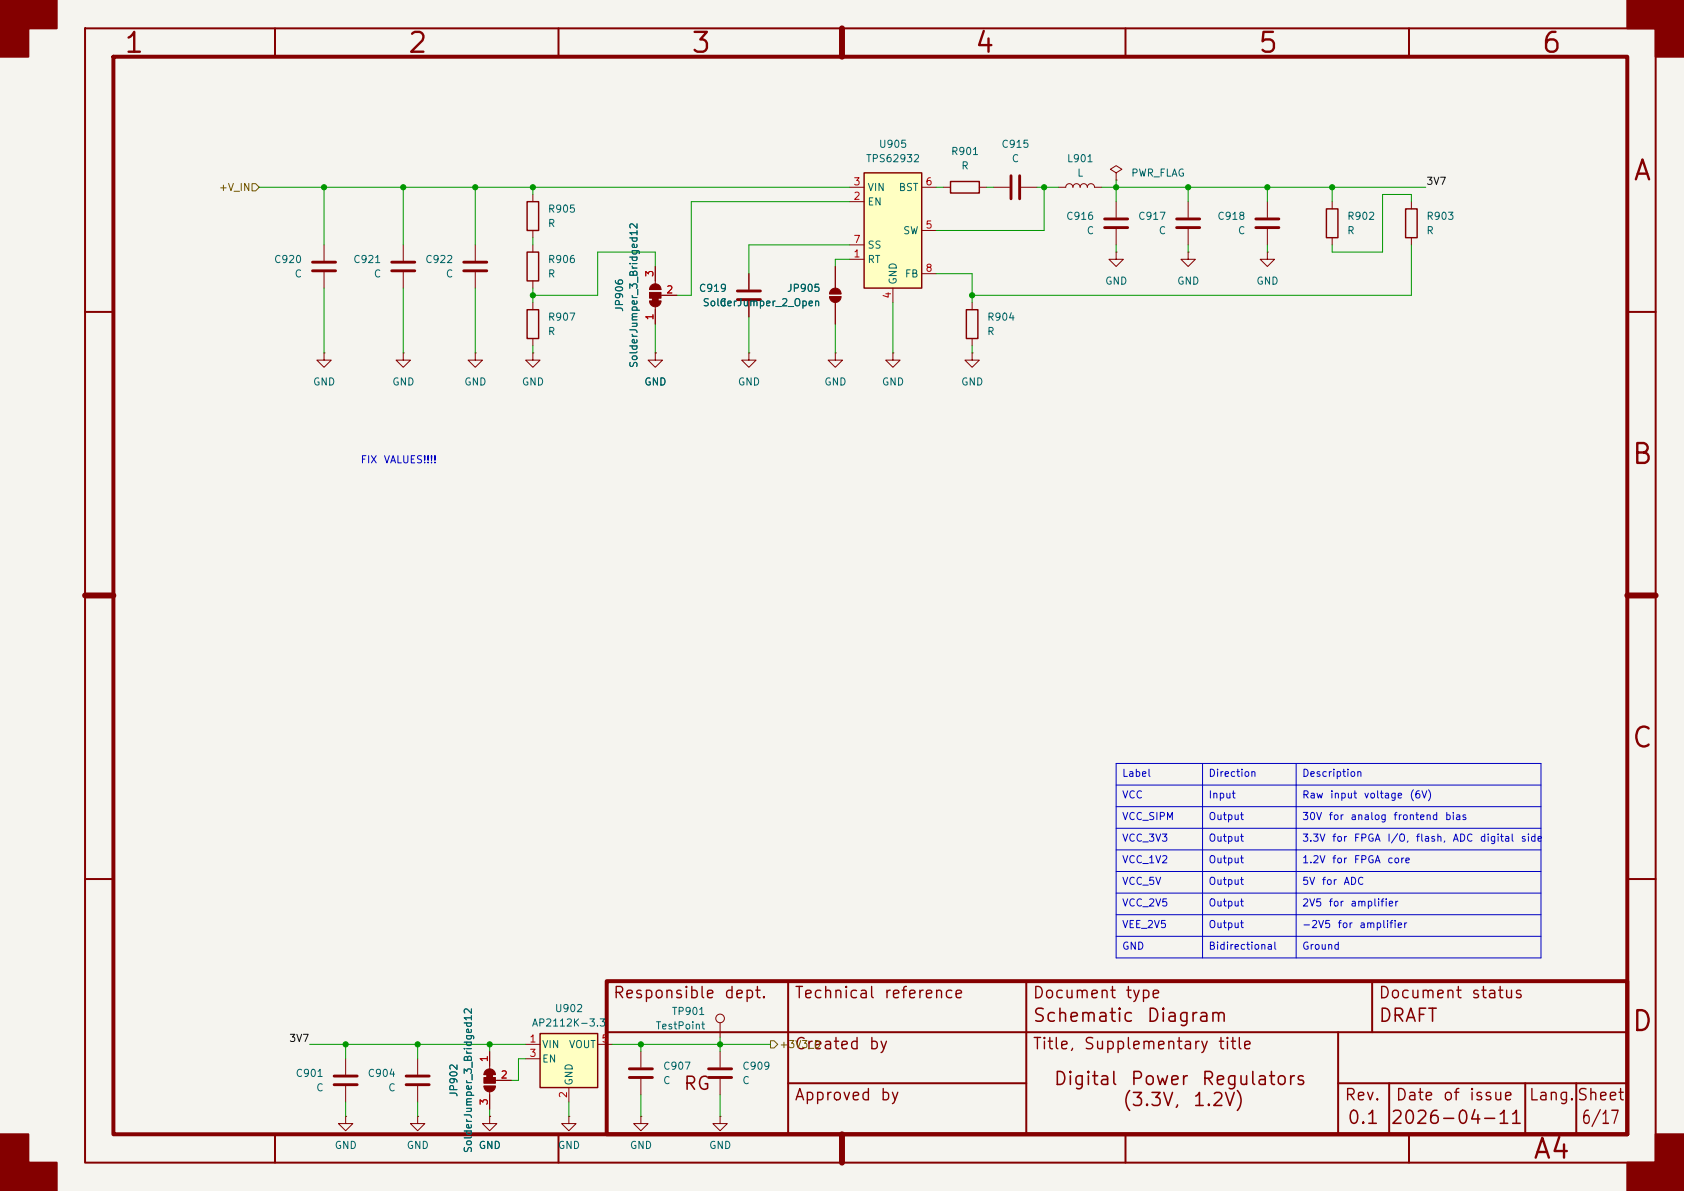
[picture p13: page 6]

VCC_1V2 | Output | 1.2V for FPGA core

VCC_5V | Output | 5V for ADC

Responsible dept. TP901 | Technical reference | Document type Schematic Diagram | Document status DRAFT

VIN 1 GND EN 3 | | C907 C | | Created by | Title, Supplementary title Digital Power Regulators (3.3V, 1.2V)

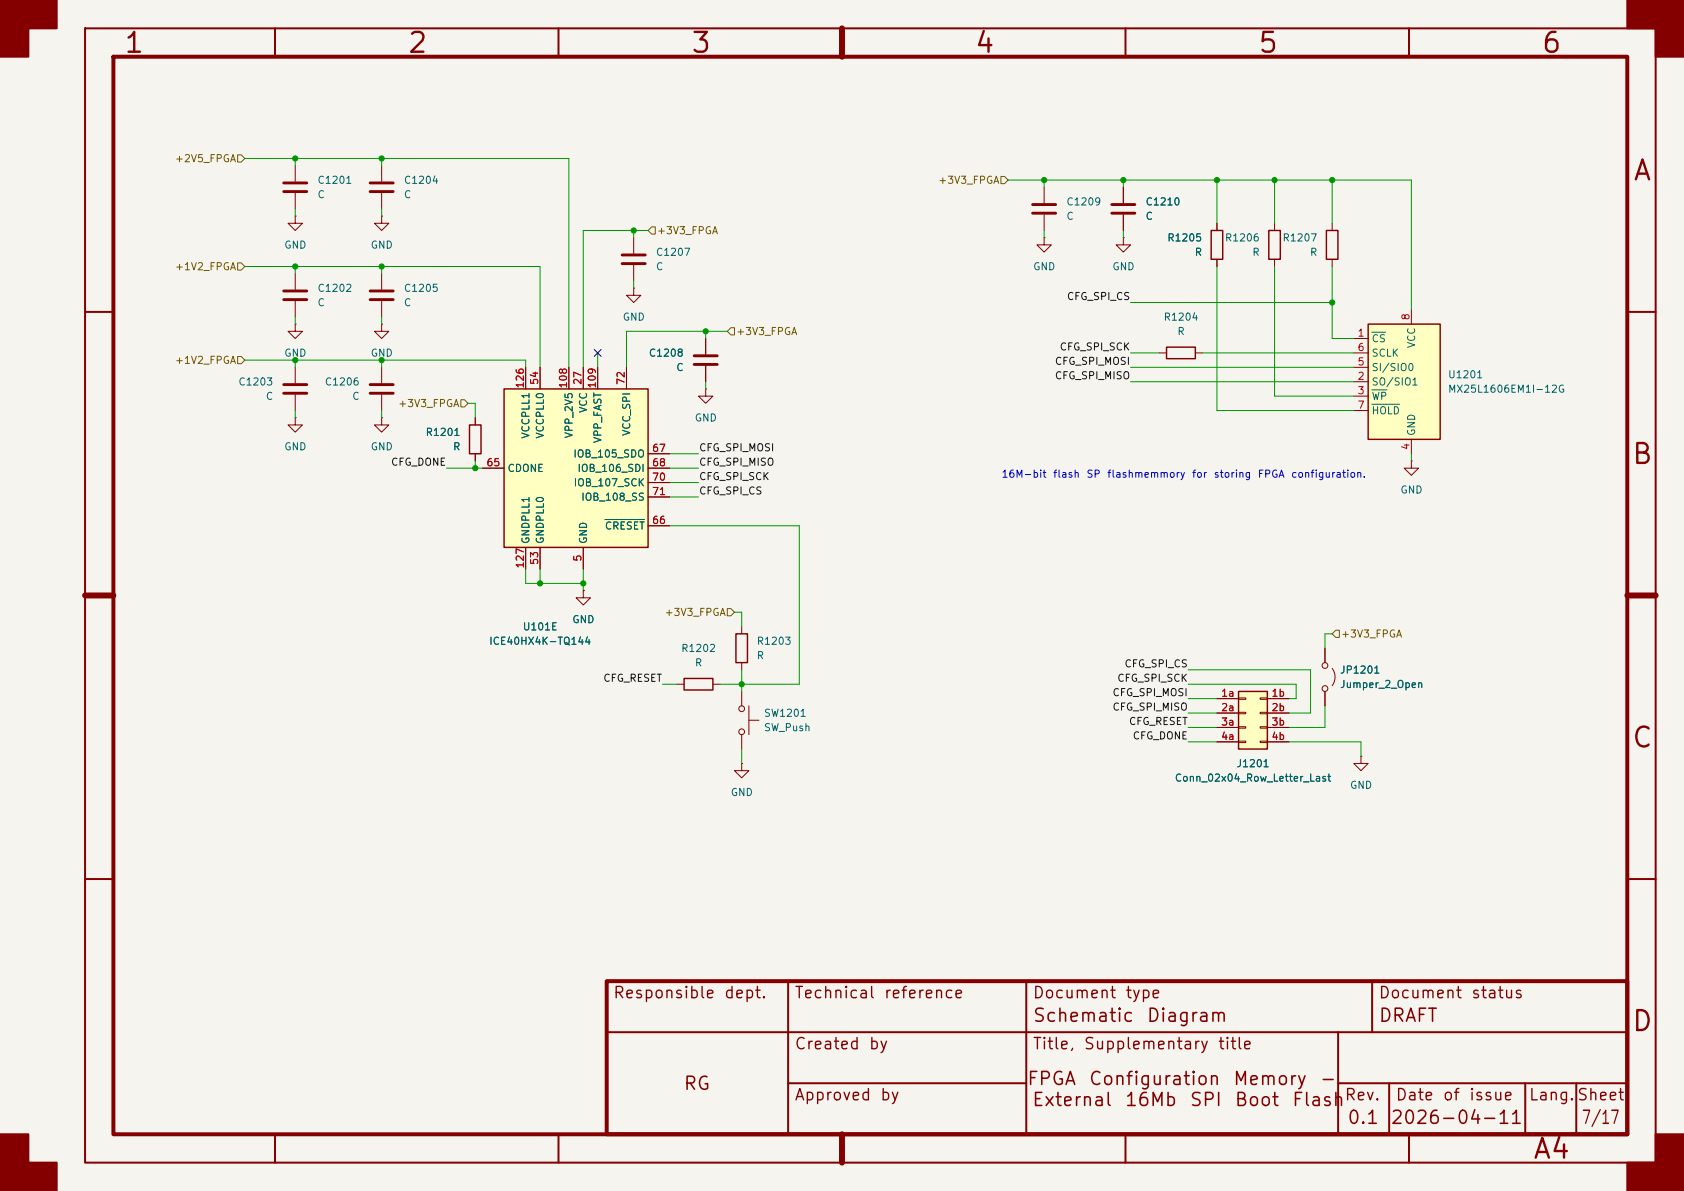
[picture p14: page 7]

16M-bit flash SP flashmemmory for storing FPGA configuration. R1201R

Responsible dept. | Technical reference | Document type Schematic Diagram | Document status DRAFT

Created by | Title, Supplementary title

FPGA Configuration Memory - External 16Mb SPI Boot Flash

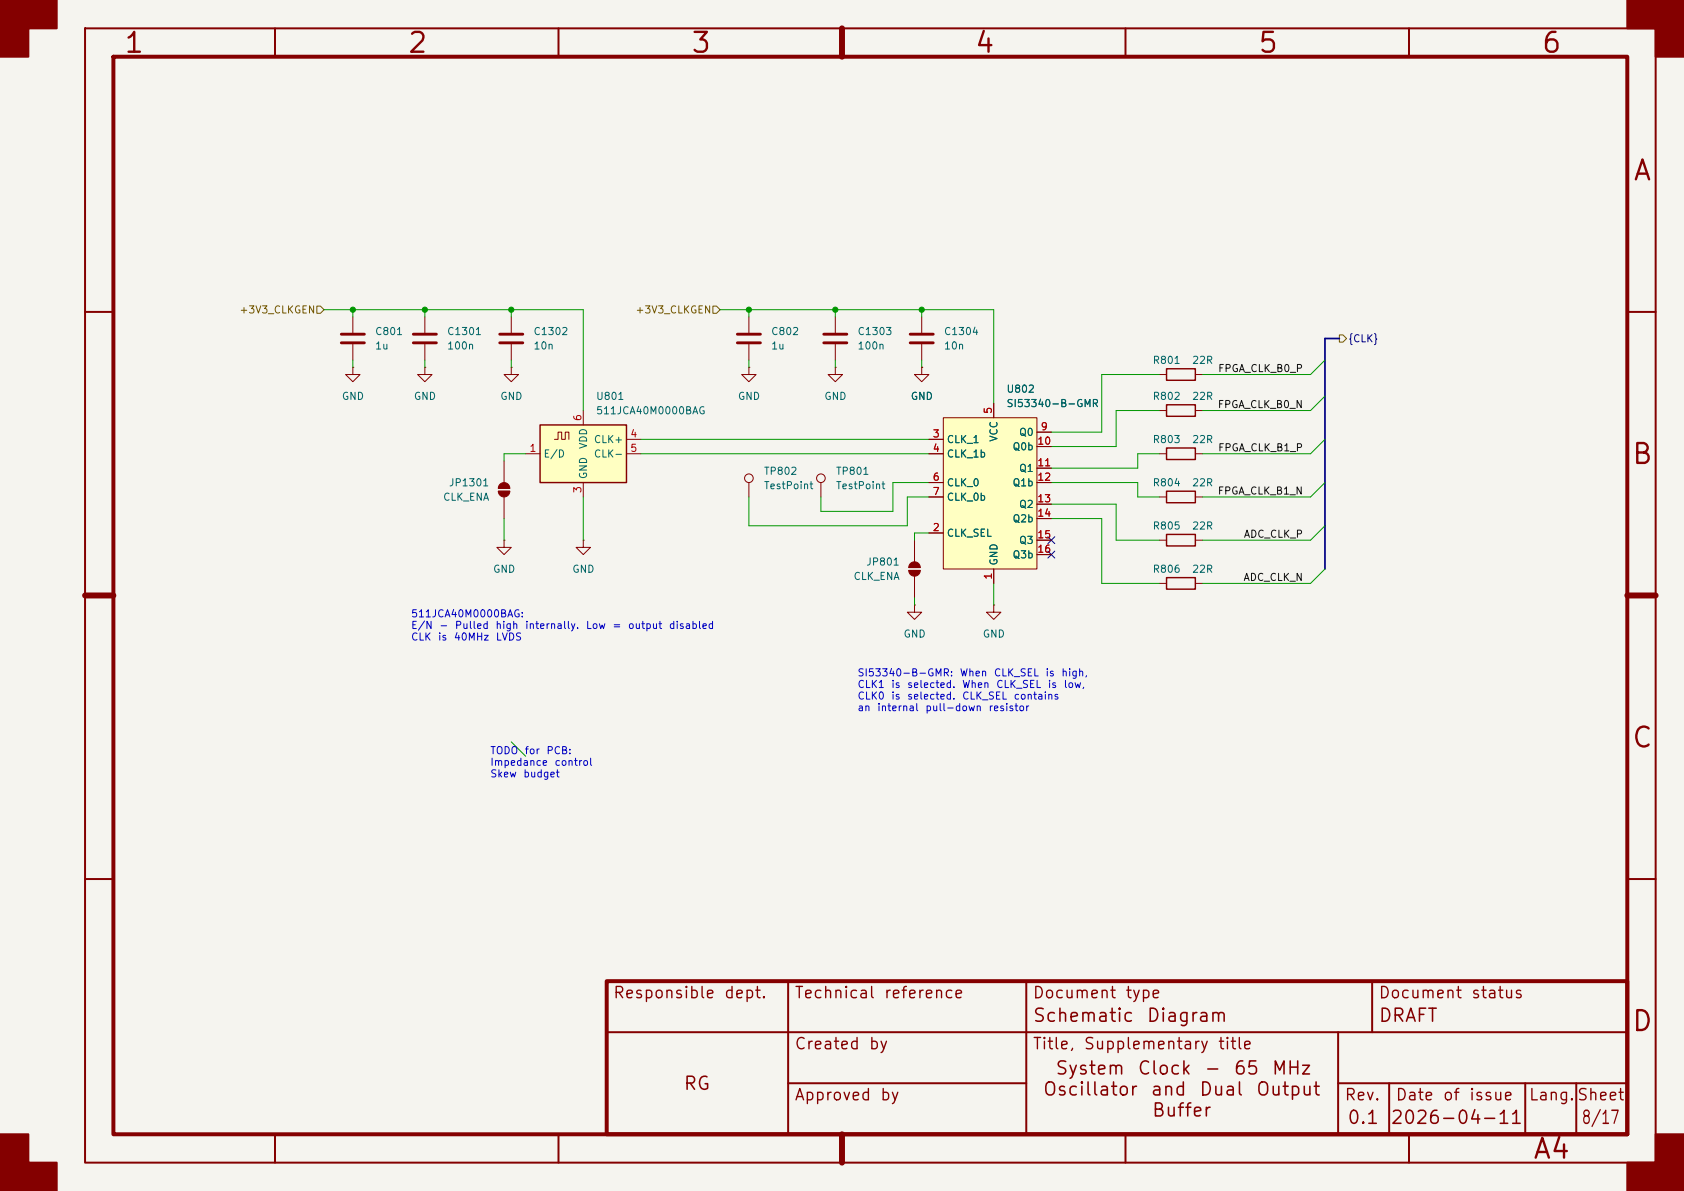
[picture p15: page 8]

511JCA40M0000BAG: E/N - Pulled high internally. Low = output disabled CLK is 40MHz LVDS

SI53340-B-GMR: When CLK_SEL is high, CLK1 is selected. When CLK_SEL is low, CLK0 is selected. CLK_SEL contains an internal pull-down resistor TODO for PCB:

Responsible dept. | Technical reference | Document type Schematic Diagram | Document status DRAFT

Created by | Title, Supplementary title System Clock - 65 MHz Oscillator and Dual Output Buffer

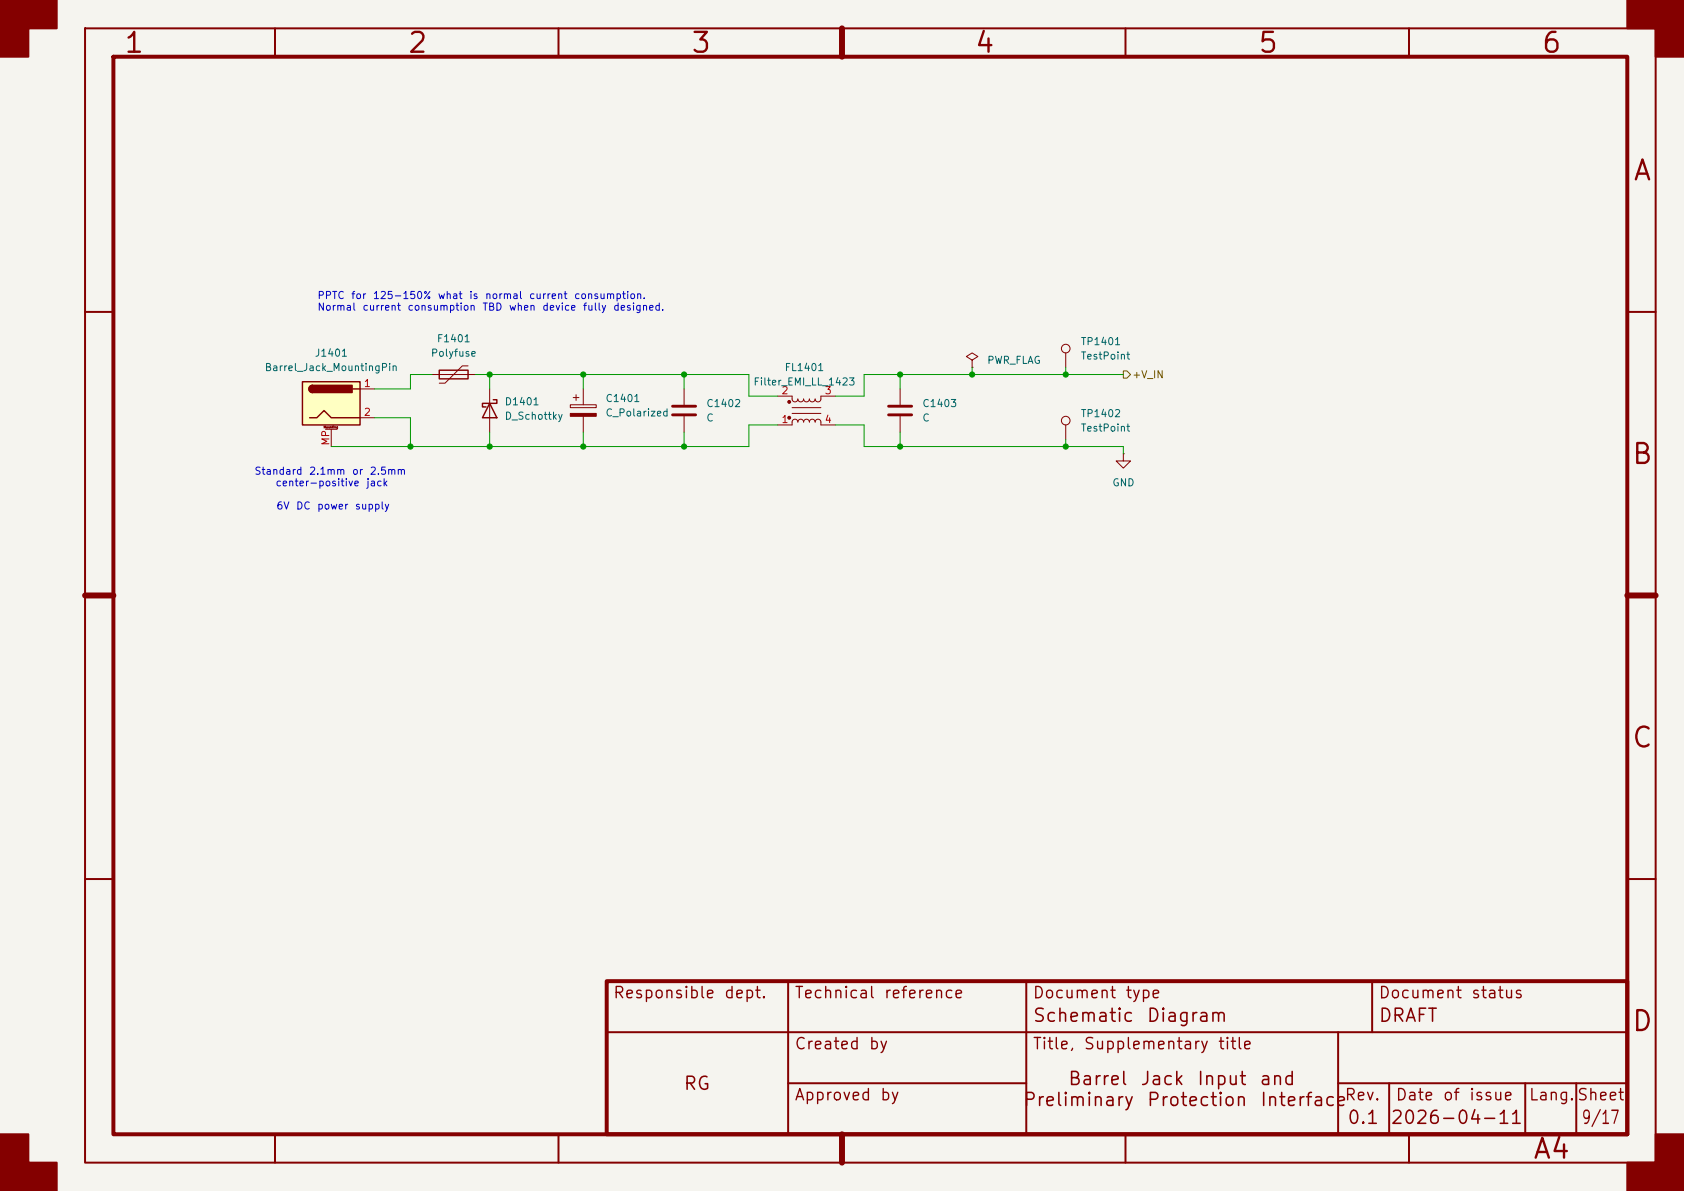
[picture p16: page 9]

PPTC for 125-150% what is normal current consumption. Normal current consumption TBD when device fully designed. Standard 2.1mm or 2.5mm center-positive jack 6V DC power supply

Responsible dept. | Technical reference | Document type Schematic Diagram | Document status DRAFT

Created by | Title, Supplementary title Barrel Jack Input and

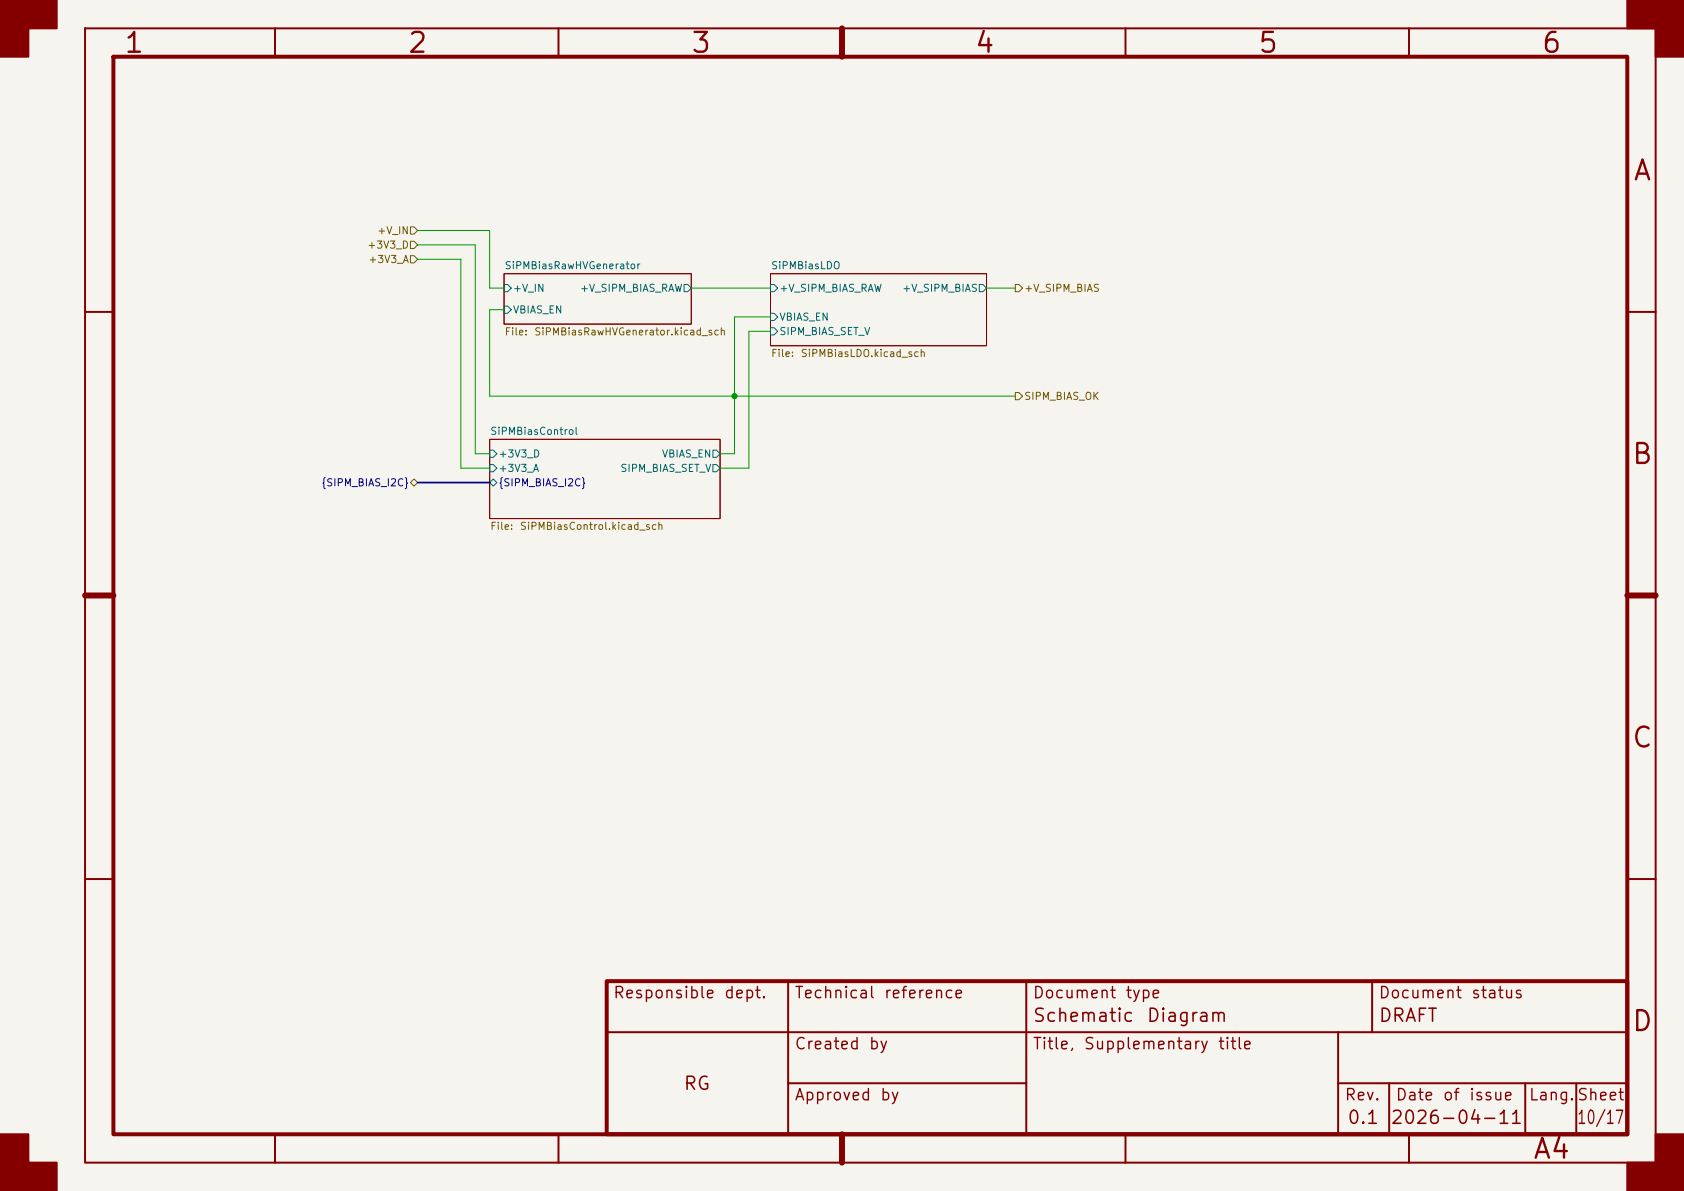
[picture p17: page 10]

Responsible dept. | Technical reference | Document type Schematic Diagram | Document status DRAFT

Created by | Title, Supplementary title

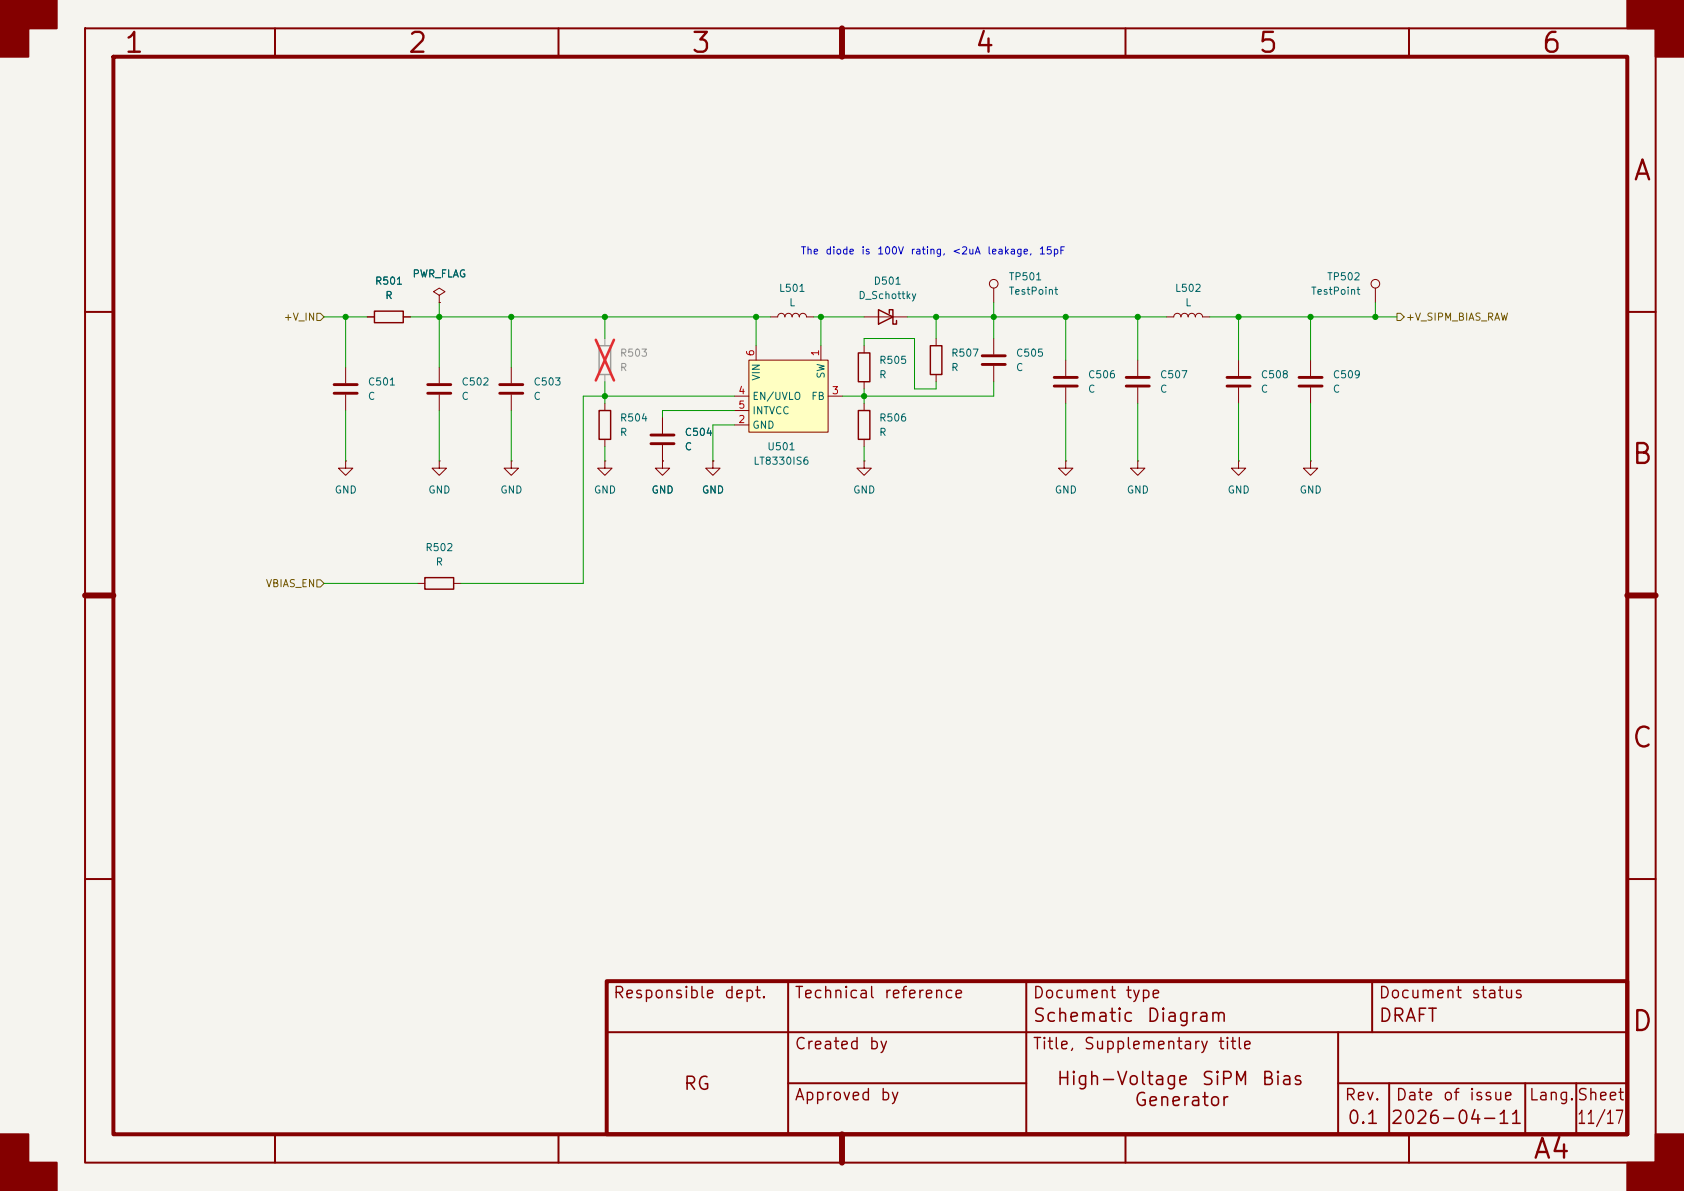
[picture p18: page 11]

The diode is 100V rating, <2uA leakage, 15pF C504 C

Responsible dept. | Technical reference | Document type Schematic Diagram | Document status DRAFT

Created by | Title, Supplementary title High-Voltage SiPM Bias Generator

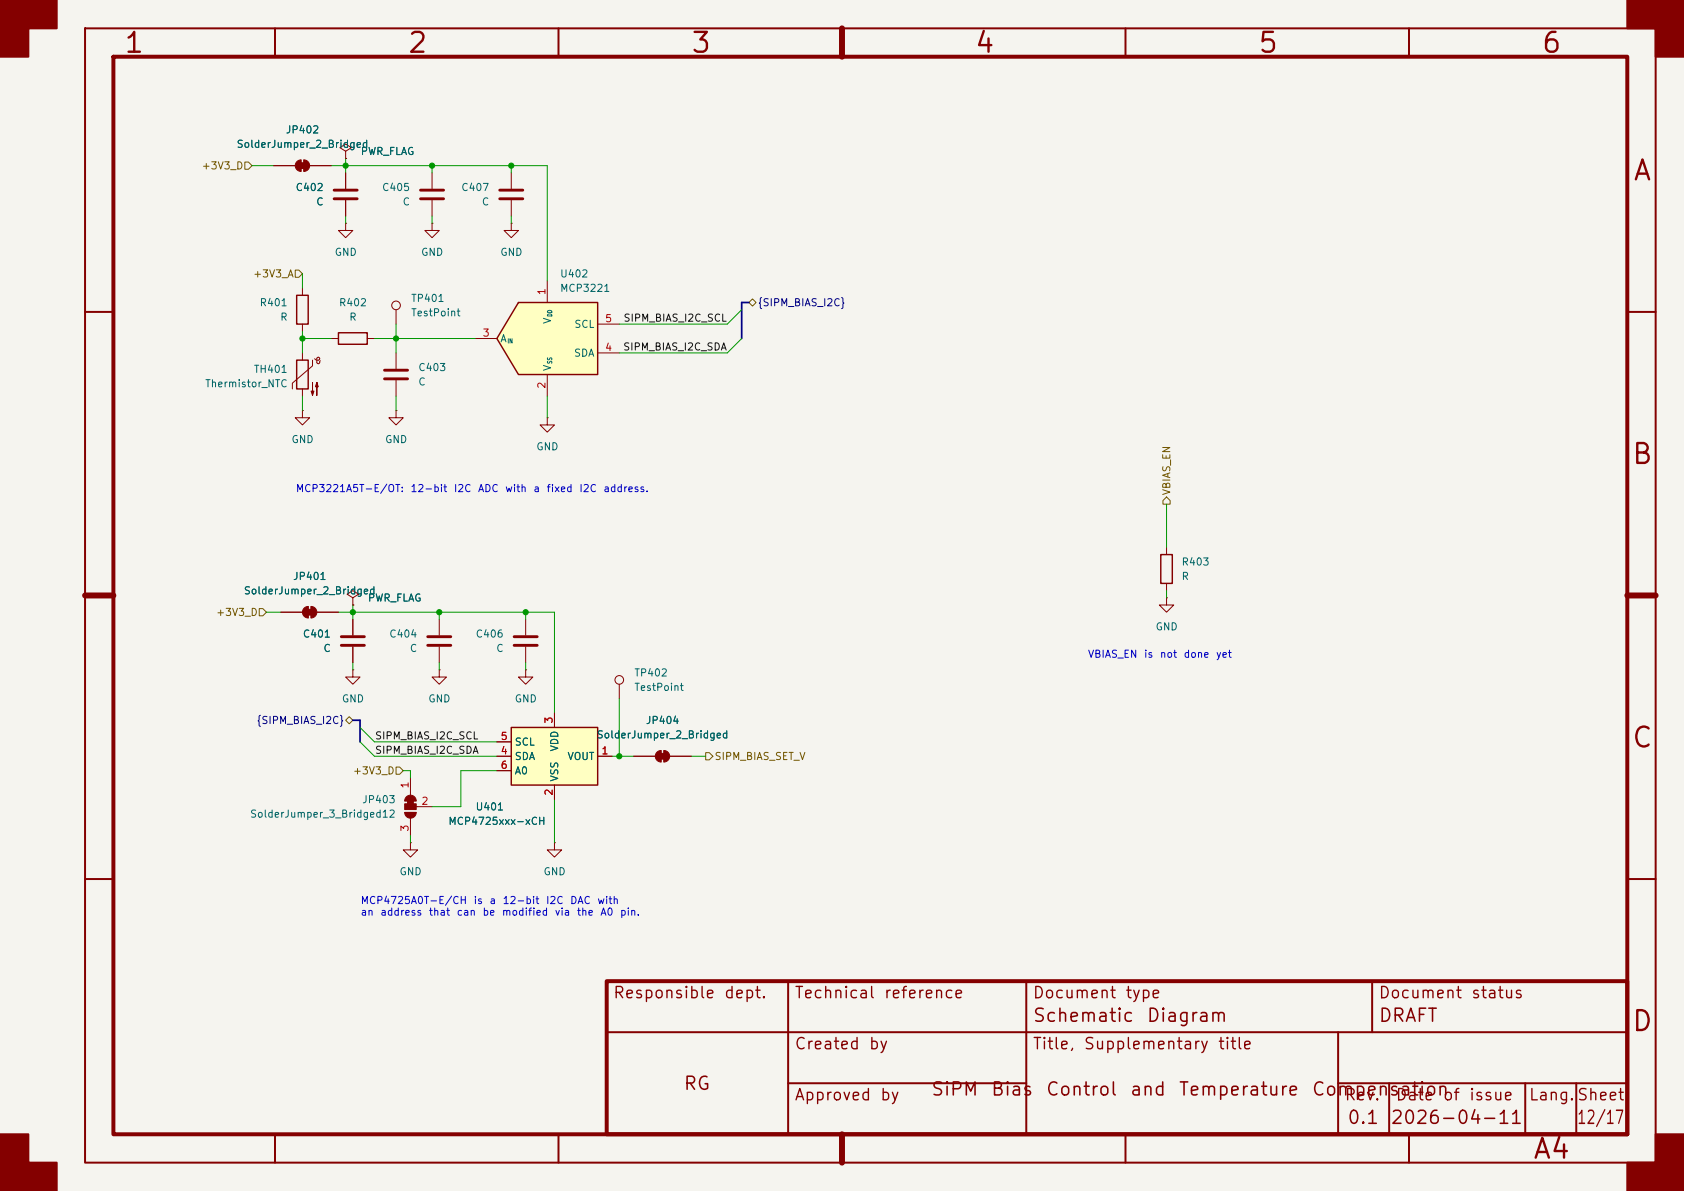
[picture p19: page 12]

Responsible dept. | Technical reference | Document type Schematic Diagram | Document status DRAFT

Created by | Title, Supplementary title

SiPM Bias Control and Temperature Compensation


Responsible dept. | Technical reference | Document type Schematic Diagram | Document status DRAFT

Created by | Title, Supplementary title

Ultra-Low Noise LDO for SIPM


to the IC that is supplied by this stabilizer on the PCB. OUTS is a sensor pin. Should be connected close

to the IC that is supplied by this stabilizer on the PCB. R1408 R

to the IC that is supplied by this stabilizer on the PCB. LT3042 calculation: Rset = abs(Vout) / 100uA

Responsible dept. | Technical reference | Document type Schematic Diagram | Document status DRAFT

For: for 60 mA: Rilim = 125 / 60 = 2.08k

for 70 mA: Rilim = 125 / 70 = 1.79k
for 100 mA: Rilim = 125 / 100 = 1.24k PG not used -> leave PG floating PGFB not used -> tie PGFB to IN

Created by | Title, Supplementary title Analog Power

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

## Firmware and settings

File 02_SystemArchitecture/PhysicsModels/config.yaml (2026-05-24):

resolution_geometry_study:

    # --------------------------------------------
    # Physics Parameters
    # --------------------------------------------
    physics:
      energy_mev: 0.662       # Reference gamma energy (Cs-137)
      # For 6 x 6 mm (MICROFC‑60035‑SMT):
      # 
      # PDE = 31% typical at Vbr + 2.5 V
      # PDE = 41% typical at Vbr + 5.0 V
      # Source: Page 2, Table 1, Rev. 9 datasheet
      pde: 0.35
      optical_efficiency: 0.7
    
    # --------------------------------------------
    # Scintillator Properties
    # --------------------------------------------
    scintillators:
      NaI(Tl):
        light_yield_ph_per_mev: 38000
      LaBr3(Ce):
        light_yield_ph_per_mev: 63000
    
    geometry:
      crystal_diameters_mm: [25.4]
      sipm_sizes_mm: [3.0, 6.0, 12.0] # 12mm corresponds to 4 x 6 mm SiPM array



# --------------------------------------------
# SiPM Area Impact Study
# --------------------------------------------

sipm_array_spectrum_study:

    rng_seed: 55
    
    energy_axis:
      max_kev: 2000
      bins: 4096
    
    simulation:
      events_per_peak: 20000
      background_rate: 5
      seed: 42
    
    detector_model:
      fwhm_single_662: 0.12
    
    sipm_arrays:
      "1 x 6x6mm":
        n_sipm: 1
      "4 x 6x6mm":
        n_sipm: 4
      "6 x 6x6mm":
        n_sipm: 6
    # --------------------------------------------
    # Isotope Lines
    # --------------------------------------------
    # Format: energy_keV, relative_intensity
    # Sources: common calibration and environmental lines
    isotopes:
      - energy_kev: 59.5
        intensity: 0.6
        label: "Am-241"
      - energy_kev: 295.0
        intensity: 0.4
        label: "Bi-214"
      - energy_kev: 352.0
        intensity: 0.5
        label: "Pb-214"
      - energy_kev: 356.0
        intensity: 0.6
        label: "Ba-133"
      - energy_kev: 511.0
        intensity: 0.7
        label: "annihilation"
      - energy_kev: 583.0
        intensity: 0.6
        label: "Tl-208"
      - energy_kev: 609.0
        intensity: 0.8
        label: "Bi-214"
      - energy_kev: 662.0
        intensity: 1.0
        label: "Cs-137"
      - energy_kev: 911.0
        intensity: 0.5
        label: "Ac-228"
      - energy_kev: 1120.0
        intensity: 0.5
        label: "Bi-214"
      - energy_kev: 1173.0
        intensity: 0.8
        label: "Co-60"
      - energy_kev: 1274.0
        intensity: 0.7
        label: "Na-22"
      - energy_kev: 1332.0
        intensity: 0.8
        label: "Co-60"
      - energy_kev: 1460.0
        intensity: 0.7
        label: "K-40"
      - energy_kev: 1764.0
        intensity: 0.6
        label: "Bi-214"


# --------------------------------------------
# Dark Count Noise Study
# --------------------------------------------

dark_count_study:

  rng_seed: 55

  detector:
    n_sipm: 4
    pe_per_kev_single: 0.59
    integration_time_s: 1.0e-6
    label: "4 x MICROFC-60035-SMT"

  energy_axis:
    e_max: 200.0
    n_bins: 800

  simulation:
    events_per_peak: 15000
    temperatures_c: [3, 21, 35]

  isotopes:
    - energy_kev: 5.9
      intensity: 1.0
      label: "Fe-55"

    - energy_kev: 13.5
      intensity: 0.7
      label: "Am-241"

    - energy_kev: 22.0
      intensity: 0.8
      label: "Cd-109"

    - energy_kev: 30.0
      intensity: 0.6
      label: "Ba-133"

    - energy_kev: 59.5
      intensity: 0.8
      label: "Am-241"

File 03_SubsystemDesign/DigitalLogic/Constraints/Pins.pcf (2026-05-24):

# ==============================================================================
# GammaSpectrometer - Pin Constraints
# Target: iCE40HX4K-TQ144
# ==============================================================================

# ------------------------------------------------------------------------------
# Clock and Reset
# ------------------------------------------------------------------------------
set_io CLK12MHZ     49
set_io RESETN       48

# ------------------------------------------------------------------------------
# SPI Interface (to ADC)
# ------------------------------------------------------------------------------
set_io SPISCLK      1
set_io SPIMOSI      2
set_io SPIMISO      3
set_io SPICSN       4

# ------------------------------------------------------------------------------
# UART Interface
# ------------------------------------------------------------------------------
set_io UARTTX       7
set_io UARTRX       8

# ------------------------------------------------------------------------------
# Status LEDs
# ------------------------------------------------------------------------------
set_io LED_OPERATIONAL      44
set_io LED_PULSE_DETECTED   45
set_io LED_SIPM_OVERLIGHTED 47
set_io LED_SIPM_OVERHEAT    47
# ------------------------------------------------------------------------------
# Debug Outputs
# ------------------------------------------------------------------------------
set_io DEBUGOUT[0]  37
set_io DEBUGOUT[1]  38
set_io DEBUGOUT[2]  41
set_io DEBUGOUT[3]  42

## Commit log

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2020-06-01 initial version rework
    [DataAcquisition.sch, DataProcessing.sch, HighVoltagePowerSupply.sch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]
2020-06-06 draft of hw power supply
    [DataAcquisition.sch, DataProcessing.sch, HighVoltagePowerSupply.sch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]
2020-06-06 add element/footprint for photomultiplier
    [PhotompultiplierInputCircuit.sch, PhotomultiplierRadioactivityDetector.kicad_pcb]
2020-06-06 draft based on my ionization chamber project
    [doxygen.cfg]
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2020-06-07 add missing footprints
    [Amplification.sch]
2020-06-07 reworked power supply for tube
    [Amplification.sch, PhotompultiplierInputCircuit.sch, PhotomultiplierRadioactivityDetector.kicad_pcb]
2020-06-13 placement of components for tube driver
    [HighVoltagePowerSupply.sch, PhotompultiplierInputCircuit.sch, PhotomultiplierRadioactivityDetector.kicad_pcb]
2020-06-14 split for continous and pulse mode
    [Amplification.sch, ContinuousMode.sch, DataAcquisition.sch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]
2020-06-14 fix for sheet filename
    [PhotomultiplierRadioactivityDetector.sch]
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2020-06-14 first try of reseting charge opamp cap
2020-06-16 reseting cap in charge amplifier works a bit
2020-06-18 correctly simulate problem with resisstor in paraller to capacitor in charge amplifier circuit
2020-06-20 working version of charge opamp reset
2020-06-21 simplify reset of charge amplifier
2020-06-27 add element,, footprint and 3d model for transformer
    [ContinuousMode.sch, DataAcquisition.sch, HighVoltagePowerSupply.sch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]
2020-06-27 draft of modules placement
    [DataAcquisition.sch, PhotomultiplierRadioactivityDetector.kicad_pcb]
2020-06-28 draft of simulation for hw power supply elements values
    [HighVoltagePowerSupply.sch, PhotomultiplierRadioactivityDetector.kicad_pcb]
2020-07-04 fix a circuit to power on/off a module
2020-07-15 fix footprints
    [HighVoltagePowerSupply.sch, PhotompultiplierInputCircuit.sch, PhotomultiplierRadioactivityDetector.kicad_pcb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]
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2020-07-17 remove hal for old mcu
    [doxygen.cfg]
2020-07-17 placement of components for hw generator
    [DE0703-22.step, DataProcessing.sch, HighVoltagePowerSupply.sch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]
2020-07-18 align to ltspice simulation
    [ContinuousMode.sch, DataAcquisition.sch, PhotomultiplierRadioactivityDetector.kicad_pcb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]
2020-07-19 simplify continous mode circuit
    [ContinuousMode.sch, PhotomultiplierRadioactivityDetector.kicad_pcb]
2020-10-24 rename project, update README.md and docs
    [ContinuousMode.sch, DE0703-22.step, DataAcquisition.sch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]
2020-10-26 add mechanical draft of the device (placement and shapes of used elements, their placement)
    [MechanicOverview.scad, Transformer_750311771.FCStd, Transformer_750311771.scad]
2020-10-27 design splitted to separate files, improved chassis holders
    [HorizontalRods.scad, MechanicOverview.scad, PCBChassis.scad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]
2020-10-28 Add workaround to export multiple .stl files from .scad file, add linter for Python scripts
    [MechanicOverview.scad]
2020-10-28 add render of the whole device
    [WholeDevice.blend]
2020-11-03 split (previousle one) pcb project to three separate pcbs
    [ContinuousMode.sch, DE0703-22.step, DataAcquisition.kicad_pcb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]
2020-11-03 finished circuit for tube polarization, in script for polar placements added PoC of generating pcb outlines using arcs and lines
    [HighVoltageConnector.sch, NegativePolarity.sch, OutputSignalConnector.sch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]
2020-11-04 finished script for automatic component placement - it was overengineering, abandonend ide aof a circular pcb for photomultiplier connector
    [HighVoltageConnector.sch, Mechanic.sch, NegativePolarity.sch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]
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2020-11-05 add calculation of (some) components of LT3580 (chip used to generate high voltage for photomultiplier). Update README.md about used microcontroler and user interface, paritialy create circuit for hi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
    [HighVoltagePowerSupply.sch]
2020-11-06 finish model to calculate dc/dc converter element values, fix way how dc/dc chip is turned on/off, add current monitoring to dc/dc converter pcb, so that it will be possible to turn it off if the out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
    [HighVoltagePowerSupply.sch]
2020-11-06 add correct footprints to some of components, add basic placement of components on pcb
    [HighVoltagePowerSupply.kicad_pcb, HighVoltagePowerSupply.sch]
2020-11-07 Choose op-amp for hv power supply board (fix: #67)
    [HighVoltagePowerSupply.kicad_pcb, HighVoltagePowerSupply.sch]
2020-11-07 Split components in architecture overview so that they match split of original single PCB design into multiple PCBs. (fix: #61)
2020-11-07 Need unity gain opampfor opamp buffer, MCP6V51 choosed
    [HighVoltagePowerSupply.sch]
2020-11-08 1. GA3459-BL transformwer will be used for hv power supply, added it to the circuit (fix: #7). 2. Status of hv power supply (output voltage, temperature, input current) will be send in an analog way 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
    [HighVoltagePowerSupply.kicad_pcb, HighVoltagePowerSupply.sch, Transformer_750311771.FCStd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]
2020-11-08 Chose correct PCB outlines based on mechanical overview (fix: #50).
    [HighVoltagePowerSupply.kicad_pcb, HighVoltagePowerSupply.sch, MechanicOverview.scad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]
2020-11-08 Draft of components placement for hv power supply, also added 3d models for those components.
    [DG300-5.0-02P-12-00A.scad, DG300-5.0-02P-12-00A.step, DJNR3015-150.FCStd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]
2020-11-10 Finished PCB for HV power supply, added correct PCB outlines for acquisition PCB.
    [DG300-5.0-02P-12-00A.scad, DataAcquisition.kicad_pcb, DataAcquisition.sch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]
2020-11-11 Clarify architecture of acquisition module (#80), removed obsolete files
    [Amplifier.sch, ContinuousMode.sch, DataAcquisition.sch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]
2020-11-12 Fixed URLs and theirs descriptions, removed obsolete modeles.
    [DE0703-22.step]
2020-11-13 Rework (in progress) of HV Power Supply due to change topology to flyback (#91), added part of calcuations of components and draft of the circuit. Clarified ducumentation about used mcu. Added footpr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
    [Amplifier.sch, DataAcquisition.kicad_pcb, DataAcquisition.sch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]
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2020-11-16 Added snubbers to circuit, fixes in elements calculator.
    [HighVoltagePowerSupply.sch]
2020-11-17 Increase converter frequency, set input voltage to 12V again, calculated input, output capacitors, LC output filter. Added footprints to some elements.
    [HighVoltagePowerSupply.kicad_pcb, HighVoltagePowerSupply.sch]
2020-11-17 Removed PCB for connector to PMT because all discrete elements will be directly soldered to PMT socket, no PCB will be used. Due to that also removed Python script to calculate placement of component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
    [PhotomultiplierConnector.kicad_pcb]
2020-11-18 Draft of four stages CR-RC shaping network, it works, but correct element values TBD.
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2020-11-21 Draft of component placement after moving to flyback topology. Improved simulation (CR on input stage).
    [HighVoltagePowerSupply.kicad_pcb, HighVoltagePowerSupply.sch, LinearExtrude.step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]
2020-11-22 Improve draft of component placement for HV Power Supply, add extra EMI shield.
    [3710.16.FCStd, 3710.16.scad, DG300-5.0-02P-12-00A.scad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]
2020-11-23 HV Power Supply and DataAcquisition will be placed on the same PCB. Due to EMI it mightl be needed to mount them on separate PCB, still they will share the same layout. This will decrease amount of n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
    [3710.16.FCStd, 3710.16.step, Amplifier.sch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]
2020-11-24 Applied some remarks after second hw review (#104). Basically only removed voltage divider and replaced it by additional transformer winding.
    [HighVoltagePowerSupply.sch]
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2020-11-27 Fix for values of resistors for DC offset in MFB filter.
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2020-12-08 Output voltage is to high for a single diode, added multiple transformers windings and diode for each one, then connected outputs in series to obtain required voltage.
    [HighVoltagePowerSupply.sch]
2020-12-11 Started creating simulation of paraller stabilizer for HV power supply. Rename simulation projects to fit theirs contents. Fix broken links.
    [HighVoltagePowerSupply.sch]
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2020-12-14 Remove old version of simulation. In KiCad model added draft of HV stabilizer.
    [DataAcquisition.sch, GammaSpectrometer.sch, HighVoltagePowerSupply.sch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]
2021-07-24 draft of component placement on PCB
    [DataAcquisition.sch, GammaSpectrometer.kicad_pcb, GammaSpectrometer.sch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]
2021-08-23 switch to kicad6, version before moving to in serries 400v stabilizers
    [DataAcquisition.kicad_sch, DataAcquisition.sch, GammaSpectrometer.kicad_pcb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]
2021-08-24 fixed footprints
    [GammaSpectrometer.kicad_pcb, GammaSpectrometer.kicad_sch, HighVoltagePowerSupply.kicad_sch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]
2021-10-09 beggining draft of in-series hv power supply
    [GammaSpectrometer.kicad_pcb, GammaSpectrometer.kicad_sch, HighVoltagePowerSupply.kicad_sch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]
2026-03-22 remove obsolete v1.0 files
    [3710.16.FCStd, 3710.16.scad, 3710.16.step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]
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2026-03-22 simulate current protection for the sensor diode
    [AnalogFrontEnd.kicad_pcb, AnalogFrontEnd.kicad_sch, DigitalProcessingUnit.kicad_pcb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]
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2026-03-28 fix: #128
    [Amplifier.kicad_sch, AnalogFrontEnd.kicad_sch, BiasSupply.kicad_sch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]
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2026-03-28 fix: #129, fix: #127
    [Amplifier.kicad_sch, BiasSupply.kicad_sch, DataAcquisitionUnit.kicad_pcb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]
2026-03-30 fix: #141, fix: #143, fix: #148
    [Pins.pcf]
2026-04-04 fix: #132
    [ADC.kicad_sch, Amplifier.kicad_sch, DataAcquisitionUnit.kicad_sch]
2026-04-05 fix: #133, fix: #157
    [ADC.kicad_sch, AFE.kicad_sch, Amplifier.kicad_sch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]
2026-04-06 fix: #145, fix: #159
    [ADC.kicad_sch, AFE.kicad_sch, AnalogPowerNegative.kicad_sch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]
2026-04-12 fix: #160, fix: #163, fix: #164
    [ADC.kicad_sch, AFE.kicad_sch, AnalogPower.kicad_sch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]
2026-04-12 fix: #134
    [ADC.kicad_sch, AFE.kicad_sch, AnalogPower.kicad_sch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]
2026-04-22 fix: #170, fix: #144, fix: #132
    [ADC.kicad_sch, AFE single channel.kicad_pcb, AFE single channel.kicad_sch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]
2026-04-23 fix: #176
    [ClockGeneration.kicad_sch]
2026-04-29 fix: #182, fix: #201, fix: #202, fix: #206
    [ADC.kicad_sch, AFE single channel.kicad_pcb, AFE single channel.kicad_sch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]
2026-05-01 fix: #169, fix: #209, fix: #210
    [AD9238.csv, ADC.kicad_sch, AFE single channel.kicad_pcb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]
2026-05-04 fix: #213
    [sss.kicad_pcb, sss.kicad_sch]
2026-05-23 fix: #232
    [AD9238.csv, ADC.kicad_sch, AFE single channel.kicad_pcb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]
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
